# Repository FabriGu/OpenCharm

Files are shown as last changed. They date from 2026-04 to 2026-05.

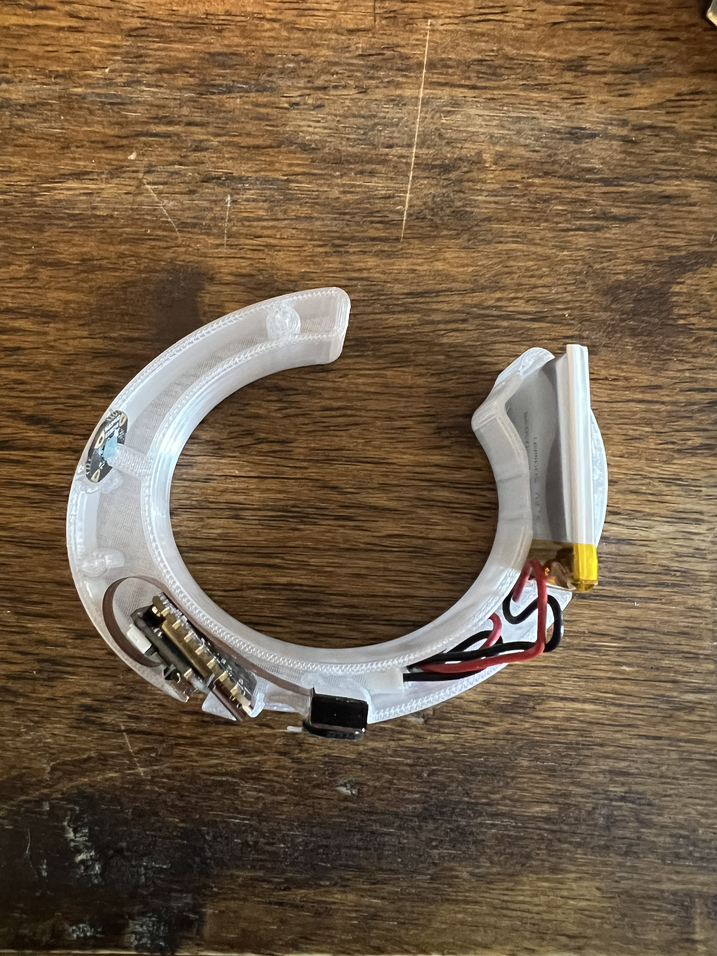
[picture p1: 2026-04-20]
assets/V0.1_Prototype/IMG_8304 2.jpeg

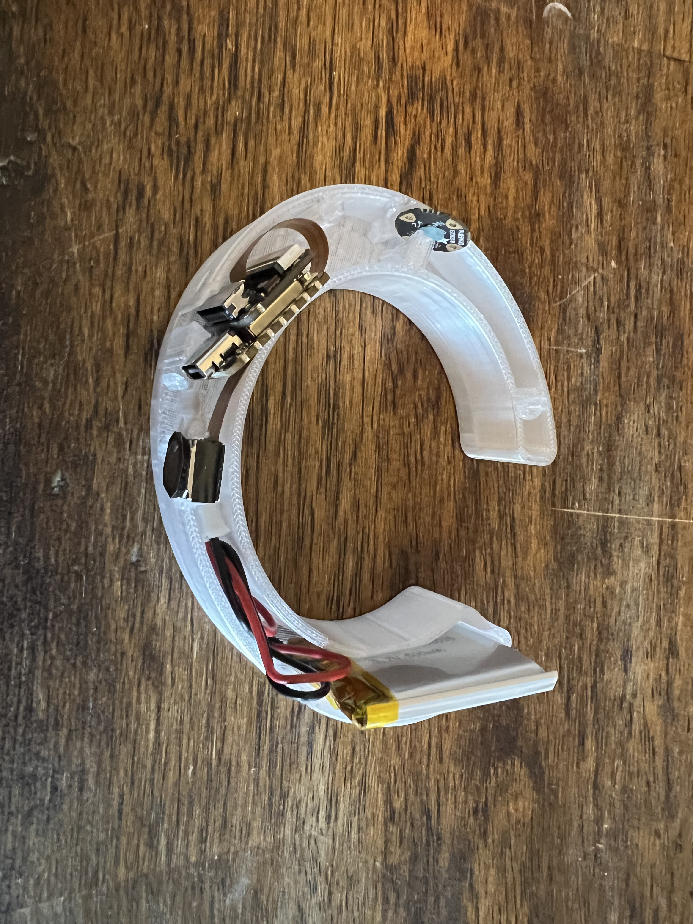
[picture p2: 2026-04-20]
assets/V0.1_Prototype/IMG_8305 2.jpeg

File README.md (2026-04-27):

# OpenCharm

A wearable that lets you talk to AI without being at your computer.

## The Idea

You shouldn't have to be sitting at a desk to use AI tools. OpenCharm is a tiny wrist-worn device that listens for voice commands, records what you say, and sends it to an AI agent that actually does stuff for you — runs commands, writes files, whatever you need. Results come back to your phone via Telegram.

Walk around. Be outside. Be cooking. Be anywhere. Touch grass. Just talk to your wrist and things happen on your machine.

## How It Works

```
┌──────────────────────────────────────────────┐
│      XIAO ESP32S3 Sense (on your wrist)      │
│  keyword spotting · mic · camera · LED       │
└──────────────────┬───────────────────────────┘
                   │ WiFi HTTP POST
                   ▼
┌──────────────────────────────────────────────┐
│       Relay Server (on your laptop)          │
│  Whisper transcription · session mgmt        │
│  Claude Code executor · Telegram bot         │
└──────────┬───────────────────┬───────────────┘
           │                   │
           ▼                   ▼
    Claude Code CLI      Telegram Bot
    (executes tasks)     (sends results)
```

1. **Say a keyword** — the bracelet runs an Edge Impulse ML model on-device to detect `RECORD`, `STOP`, `CAPTURE`, or `POST`.
2. **Record audio or snap a photo** — audio is captured at 16 kHz 16-bit mono; photos at 640x480 JPEG.
3. **Upload over WiFi** — the bracelet HTTP-POSTs the file to a FastAPI relay server on your local network.
4. **Transcribe and execute** — the relay runs Whisper (local, no API cost) to transcribe speech, then feeds the request to Claude Code.
5. **Get notified** — results are pushed to your phone via Telegram.

### Interaction Modes

| Input | Trigger | What happens |
|---|---|---|
| Voice command | Say **"Record"** → speak → say **"Stop"** (or 30 s timeout) | Audio recorded, uploaded, transcribed, executed |
| Photo | Say **"Capture"** | 3-second LED countdown, then JPEG captured and uploaded |
| Session | Buffer multiple audio/image captures, then say **"Post"** | Accumulated content sent as one batch to the AI |

## Why

AI tools are powerful but they chain you to a keyboard and screen. This project breaks that chain. It's about **freedom** — accessing the same AI capabilities from anywhere in your space, hands-free, eyes-free.

## Tech Stack

| Layer | Technology | Details |
|---|---|---|
| **MCU** | XIAO ESP32S3 Sense | 240 MHz dual-core, 8 MB flash, PSRAM, built-in mic + camera |
| **ML** | Edge Impulse / TFLite Micro | On-device keyword spotting (4 keywords + noise/unknown) |
| **Speech-to-Text** | faster-whisper | Runs locally on your laptop — no cloud API costs |
| **AI Execution** | Claude Code CLI | Subprocess with JSON stdin/stdout |
| **Relay Server** | Python / FastAPI | Async HTTP, session management, Telegram integration |
| **Notifications** | Telegram Bot API | Push results to your phone |
| **Firmware** | Arduino / PlatformIO | C++ with FreeRTOS on Core 1 for inference |

## Project Structure

```
OpenCharm/
├── firmware/                   ESP32S3 firmware (Arduino/PlatformIO)
│   ├── platformio.ini
│   ├── include/
│   │   └── config.h            WiFi, pin, ML threshold configuration
│   ├── lib/
│   │   └── ei-keyword-spotting/ Edge Impulse TFLite model library
│   └── src/
│       └── main.cpp            Main firmware: keywords, recording, camera, WiFi
│
├── relay/                      Python relay server
│   ├── relay_server.py         FastAPI server (audio upload, transcription, execution)
│   ├── claude_executor.py      Claude Code subprocess executor
│   ├── intent_parser.py        Voice command intent parsing
│   ├── requirements.txt
│   └── README.md
│
├── scripts/
│   ├── recording/              Serial audio recording utilities
│   │   ├── record_serial.py
│   │   ├── sample_recorder_local.py
│   │   └── recorder_firmware/
│   └── training/               ML training automation
│       ├── train_model.py      Automated Edge Impulse pipeline
│       ├── generate_tts_samples.py  Synthetic voice data via Google TTS
│       ├── clean_upload.py
│       └── requirements.txt
│
├── cad/                        3D-printable enclosure
│   └── V1/                     STL + STEP files (left/right halves)
│
├── docs/                       Documentation
│   ├── quick-start.md
│   ├── architecture.md
│   ├── network-architecture.md
│   ├── keyword-detection.md
│   ├── latency-analysis.md
│   ├── bom.md
│   └── ...
│
├── assets/                     Photos and media
│   └── V0.1_Prototype/
│
├── hermes-config/              Alternative AI integration notes
│
└── LICENSE                     MIT
```

## Quick Start

### Hardware

- 1x [Seeed XIAO ESP32S3 Sense](https://wiki.seeedstudio.com/xiao_esp32s3_getting_started/)
- USB-C cable
- (Optional) 3D-printed enclosure from `cad/V1/`

See `docs/bom.md` for the full bill of materials.

### Firmware

```bash
# Install PlatformIO CLI (or use VS Code extension)
pip install platformio

# Configure WiFi and relay IP
# Edit firmware/include/config.h:
#   WIFI_SSID, WIFI_PASSWORD, RELAY_IP, RELAY_PORT

cd firmware
pio run --target upload
pio device monitor        # watch serial output
```

### Relay Server

```bash
cd relay
pip install -r requirements.txt

# Create .env with your Telegram bot token (optional)
# TELEGRAM_BOT_TOKEN=...
# TELEGRAM_CHAT_ID=...

python relay_server.py
# Server starts on http://0.0.0.0:8080
```

### ML Model Training (Optional)

Only needed if you want to retrain the keyword detection model.

```bash
cd scripts/training
pip install -r requirements.txt

# Generate synthetic training samples
python generate_tts_samples.py

# Train on Edge Impulse and download the Arduino library
python train_model.py
```

See `docs/keyword-detection.md` for model details and threshold tuning.

## API Endpoints

The relay server exposes these endpoints for the bracelet:

| Endpoint | Method | Description |
|---|---|---|
| `/health` | GET | Health check |
| `/capture/audio` | POST | Upload and transcribe a WAV file |
| `/capture/image` | POST | Upload and analyze a JPEG |
| `/session/audio` | POST | Buffer audio in current session |
| `/session/image` | POST | Buffer image in current session |
| `/session/process` | POST | Process all buffered session content |
| `/session/execute` | POST | Send accumulated context to Claude Code |

## Status

Working prototype. Voice commands, photo capture, audio recording, AI execution, and Telegram feedback all functional. Actively iterating on ML model accuracy and form factor.

## License

[MIT](LICENSE)

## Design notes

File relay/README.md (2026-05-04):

# OpenCharm Relay Server

Receives images and audio from the XIAO ESP32S3 bracelet via HTTP POST, converts audio to OGG/Opus, and forwards to Telegram where Hermes Agent processes them.

## Setup

### 1. Install Dependencies

```bash
cd relay
python3 -m venv .venv
source .venv/bin/activate
pip install -r requirements.txt
```

### 2. Install FFmpeg (for audio conversion)

```bash
# macOS
brew install ffmpeg

# Ubuntu/Debian
sudo apt install ffmpeg
```

### 3. Create Telegram Bot

1. Open Telegram and message `@BotFather`
2. Send `/newbot`
3. Choose a name (e.g., "OpenCharm")
4. Choose a username (e.g., `opencharm_bot`)
5. Copy the HTTP API token

### 4. Get Your Chat ID

1. Send any message to your new bot
2. Visit: `https://api.telegram.org/bot<YOUR_TOKEN>/getUpdates`
3. Find `"chat":{"id":123456789}` in the JSON response
4. That number is your chat ID

### 5. Configure Environment

```bash
cp .env.example .env
# Edit .env with your token and chat ID
```

### 6. Run the Server

```bash
source .venv/bin/activate
python relay_server.py
```

Or with uvicorn directly:
```bash
uvicorn relay_server:app --host 0.0.0.0 --port 8080
```

## Endpoints

| Endpoint | Method | Description |
|---|---|---|
| `/` | GET | Status and last capture info |
| `/health` | GET | Health check for bracelet |
| `/capture/image` | POST | Receive JPEG, send to Telegram |
| `/capture/audio` | POST | Receive WAV, convert to OGG, send as voice |

## Testing with curl

### Test image upload:
```bash
curl -X POST http://localhost:8080/capture/image \
  -F "image=@test.jpg"
```

### Test audio upload:
```bash
curl -X POST http://localhost:8080/capture/audio \
  -F "audio=@test.wav"
```

## Bracelet Configuration

Set these in the bracelet firmware `config.h`:

```cpp
#define RELAY_IP    "192.168.x.x"  // Your laptop's IP
#define RELAY_PORT  8080
```

Find your IP with:
```bash
# macOS
ipconfig getifaddr en0

# Linux
hostname -I
```

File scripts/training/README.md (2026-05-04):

# Edge Impulse Keyword Spotting Training

Automated training scripts for the OpenCharm keyword spotting model.

## Keywords

- **RECORD** - Start audio recording
- **STOP** - Stop recording (don't process)
- **SNAP** - Take photo with countdown
- **SEND** - Process all accumulated content with AI

## Quick Start

### 1. Install Dependencies

```bash
cd scripts/training
pip install -r requirements.txt
```

### 2. Configure Credentials

```bash
cp .env.example .env
# Edit .env with your API keys
```

**Required:**
- `EDGE_IMPULSE_API_KEY` - Get from Edge Impulse Studio > Your Project > Dashboard > Keys

**Optional (for synthetic voice generation):**
- `GOOGLE_APPLICATION_CREDENTIALS` - Path to Google Cloud service account JSON

### 3. Generate Voice Samples

**Option A: Use Google TTS (automated)**
```bash
python generate_tts_samples.py
```

**Option B: Record your own voice**
Place WAV files (16kHz, mono, 1 second) in:
```
samples/
  record/
    record_001.wav
    record_002.wav
    ...
  stop/
    stop_001.wav
    ...
  snap/
  send/
  noise/
  unknown/
```

**Option C: Both (recommended)**
Generate TTS samples, then add your own recordings for better accuracy.

### 4. Train Model

```bash
python train_model.py
```

This will:
1. Upload samples to Edge Impulse
2. Configure the impulse (MFE + Transfer Learning)
3. Train the model
4. Download the Arduino library

### 5. Install in Firmware

The script will install the library to `firmware/lib/ei-keyword-spotting-new/`.

Manually update:
1. Back up the existing `ei-keyword-spotting` library if needed
2. Rename `ei-keyword-spotting-new` to `ei-keyword-spotting`
3. Update `main.cpp` include if needed

## Manual Training (Alternative)

If the automation doesn't work, you can train manually in Edge Impulse Studio:

1. Go to https://studio.edgeimpulse.com
2. Create new project
3. Upload samples from `./samples/` directory
4. Create impulse: Time Series → MFE → Classification
5. Train model
6. Download Arduino library
7. Extract to `firmware/lib/ei-keyword-spotting/`

## Tips for Better Accuracy

1. **Add your own voice samples** - TTS is good but your voice will be more accurate
2. **Record in your environment** - Background noise matters
3. **Vary your pronunciation** - Fast, slow, loud, quiet
4. **50+ samples per keyword minimum** - More is better
5. **Good noise/unknown class** - Prevents false positives

## Troubleshooting

### "API key not found"
- Make sure `.env` file exists with your `EDGE_IMPULSE_API_KEY`
- Get key from Edge Impulse Studio > Dashboard > Keys

### "Google TTS not available"
- Install: `pip install google-cloud-texttospeech`
- Set up credentials: https://cloud.google.com/text-to-speech/docs/quickstart

### "Training failed"
- Check Edge Impulse Studio for detailed error messages
- Make sure you have enough samples (50+ per keyword)
- Try reducing training cycles if memory issues

### "Model accuracy too low"
- Add more samples, especially your own voice
- Improve unknown/noise class diversity
- Try different DSP settings (MFE vs MFCC)

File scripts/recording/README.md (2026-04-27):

# ESP32 Keyword Sample Recorder

Record training samples directly through your ESP32's microphone for better keyword detection accuracy.

## Quick Start

### 1. Find your computer's IP address

```bash
# On Mac:
ipconfig getifaddr en0
```

### 2. Update the firmware with your IP

Edit `recorder_firmware/src/main.cpp`:
```cpp
#define SERVER_IP       "YOUR_IP_HERE"  // e.g., "192.168.1.181"
```

Also verify WiFi credentials match your network.

### 3. Flash the recorder firmware

```bash
cd recorder_firmware
pio run -t upload
```

### 4. Start the recording server

```bash
# In another terminal:
python sample_server.py
```

### 5. Record samples

1. Press the **button** on ESP32
2. LED turns **RED** - say the keyword clearly
3. **GREEN flash** = sample saved
4. Repeat until all samples collected

## How it works

- ESP32 records 2.5 seconds of audio when you press the button
- Audio is sent to your computer over WiFi
- The Python server automatically:
  - Detects where your voice is in the recording (VAD)
  - Centers the word in a perfect 1-second window
  - Saves it with the correct filename
- No timing pressure on you!

## After recording

Samples are saved to:
```
scripts/training/samples/
  record/record_real_001.wav, record_real_002.wav, ...
  stop/stop_real_001.wav, ...
  capture/capture_real_001.wav, ...
  post/post_real_001.wav, ...
```

Then:
1. Go to Edge Impulse Studio
2. Delete old samples (or keep some TTS for variety)
3. Upload the new real samples
4. Retrain the model
5. Download and flash the new Arduino library

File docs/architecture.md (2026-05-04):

# OpenCharm Network Architecture Diagrams

## System Overview

```
┌─────────────────────────────────────────────────────────────────────────┐
│                            OpenCharm System                              │
└─────────────────────────────────────────────────────────────────────────┘

┌──────────────┐         ┌──────────────┐         ┌──────────────┐
│  ESP32S3     │  WiFi   │ Relay Server │ Process │ Claude Code  │
│  Bracelet    │────────▶│  (FastAPI)   │────────▶│  Subprocess  │
│              │  HTTP   │              │ stdin/  │              │
│  - Camera    │         │  - Whisper   │ stdout  │  - Bash      │
│  - Mic (PDM) │         │  - Vision AI │         │  - Edit      │
│  - Keywords  │         │  - Telegram  │         │  - Read      │
│  - LED       │◀────────│  - Claude    │◀────────│  - Write     │
└──────────────┘  200 OK └──────────────┘ JSON    └──────────────┘
                              │
                              │ Telegram API
                              ▼
                         ┌──────────────┐
                         │   Telegram   │
                         │     Bot      │
                         │ (User Feed)  │
                         └──────────────┘
```

---

## Data Flow: Voice Command Execution

```
┌─────────────────────────────────────────────────────────────────────────┐
│ Example: User says "git status"                                         │
└─────────────────────────────────────────────────────────────────────────┘

1️⃣ ESP32 CAPTURE
┌──────────────┐
│   ESP32S3    │  User speaks "git status"
│              │  ↓
│ [RECORD]     │  Keyword detected → Start recording
│ [STOP]       │  Keyword detected → Stop recording
│              │  ↓
│ 16kHz WAV    │  Build WAV file (16kHz, 16-bit, mono)
│ Audio Buffer │
└──────────────┘
       │
       │ POST /capture/audio
       │ multipart/form-data
       │ Field: audio (audio/wav)
       ▼

2️⃣ RELAY PROCESSING
┌──────────────┐
│ Relay Server │  Receive HTTP POST
│              │  ↓
│ FastAPI      │  Save temp WAV file
│ Async        │  ↓
│              │  Whisper transcription
│ [Whisper]    │  "git status" (confidence: 0.95)
│  base model  │
└──────────────┘
       │
       │ HTTP 200 OK (immediate response to ESP32)
       │
       ├─────────────────────────────────────┐
       │                                     │
       │ Background Task                     │ Main Thread
       ▼                                     ▼
┌──────────────┐                    ┌──────────────┐
│   Telegram   │                    │   ESP32S3    │
│     Bot      │                    │              │
│              │                    │ LED: Success │
│ "You said:   │                    │ (Green flash)│
│  git status" │                    └──────────────┘
└──────────────┘
       │
       │ AI Processing continues...
       ▼

3️⃣ CLAUDE CODE INTEGRATION
┌──────────────┐
│ Relay Server │  Format task prompt
│              │  ↓
│              │  {
│              │    "type": "user",
│              │    "content": "Execute: git status"
│              │  }
│              │  ↓
│ [stdin pipe] │  Write JSON + newline
└──────────────┘
       │
       │ stdin stream
       │ (subprocess.PIPE)
       ▼
┌──────────────┐
│ Claude Code  │  Parse command
│  Subprocess  │  ↓
│              │  Understand: "Run git status"
│  --print     │  ↓
│  --stream    │  Check safety:
│              │  ✅ git status (read-only, safe)
│              │  ↓
│ [Bash tool]  │  Execute: git status
│              │  ↓
│              │  Capture output:
│              │  "On branch wifi
│              │   Changes not staged:
│              │     modified: relay/.env"
└──────────────┘
       │
       │ stdout stream
       │ (JSON lines)
       ▼
┌──────────────┐
│ Relay Server │  Read stdout line-by-line
│              │  ↓
│ [stdout      │  Parse JSON response
│  reader]     │  ↓
│              │  Format for Telegram:
│              │  ```
│              │  On branch wifi
│              │  M relay/.env
│              │  ```
└──────────────┘
       │
       │ Send to Telegram
       ▼
┌──────────────┐
│   Telegram   │
│     Bot      │
│              │
│ *Git Status* │
│              │
│ ```          │
│ On branch    │
│   wifi       │
│ M relay/.env │
│ ```          │
└──────────────┘

4️⃣ COMPLETION
       │
       │ Log success metrics
       ▼
   [Complete]
   Total time: 3.5s
   - Capture: 1.0s
   - Transfer: 0.2s
   - Whisper: 1.5s
   - Claude: 0.5s
   - Telegram: 0.3s
```

---

## Data Flow: Image Analysis

```
┌─────────────────────────────────────────────────────────────────────────┐
│ Example: User says "CAPTURE" then "POST"                                │
└─────────────────────────────────────────────────────────────────────────┘

1️⃣ ESP32 CAPTURE
┌──────────────┐
│   ESP32S3    │  User says "CAPTURE"
│              │  ↓
│ [CAPTURE]    │  Keyword detected
│ countdown    │  ↓
│              │  3... 2... 1... *flash*
│ [OV2640]     │  ↓
│ Camera       │  Capture JPEG (640x480)
│              │  ↓
│ Session      │  Buffer in session (not processed yet)
│ buffer       │
└──────────────┘
       │
       │ POST /session/image
       │ (buffered, not analyzed)
       ▼
┌──────────────┐
│ Relay Server │  Store in session_buffer
│              │
│ session:     │  {
│  images: [1] │    "image_files": [
│  audio: [0]  │      {"data": bytes, "timestamp": "..."}
│              │    ]
│              │  }
└──────────────┘
       │
       │ User says "POST"
       ▼

2️⃣ SESSION PROCESSING
┌──────────────┐
│   ESP32S3    │  POST /session/process
│              │  ↓
│ [POST]       │  Trigger processing of ALL buffered content
└──────────────┘
       │
       ▼
┌──────────────┐
│ Relay Server │  Combine session content:
│              │  - 1 image (JPEG)
│              │  - 0 audio files
│              │  ↓
│              │  Prepare multi-modal prompt
└──────────────┘
       │
       │ Format for Claude Code
       ▼

3️⃣ MULTI-MODAL ANALYSIS
┌──────────────┐
│ Relay Server │  {
│              │    "type": "user",
│              │    "content": "Analyze workspace image",
│              │    "attachments": [
│              │      {
│              │        "type": "image",
│              │        "mime_type": "image/jpeg",
│              │        "data": "base64..."
│              │      }
│              │    ]
│              │  }
└──────────────┘
       │
       │ stdin
       ▼
┌──────────────┐
│ Claude Code  │  Receive image + prompt
│  Subprocess  │  ↓
│              │  Vision analysis:
│ [Vision]     │  - Sees desk with laptop
│              │  - Code on screen (C++)
│              │  - Notes: indentation inconsistent
│              │  ↓
│              │  Generate suggestion:
│              │  "Fix indentation in main.cpp lines 45-60"
│              │  ↓
│ [Edit tool]  │  Execute fix:
│              │  Edit /path/to/main.cpp
│              │  - Fix indentation
│              │  ↓
│              │  Return result:
│              │  "Fixed indentation in main.cpp"
└──────────────┘
       │
       │ stdout
       ▼
┌──────────────┐
│ Relay Server │  Parse response
│              │  ↓
│              │  Clear session buffer
│              │  ↓
│              │  Send to Telegram + ESP32
└──────────────┘
       │
       ├───────────────────┐
       │                   │
       ▼                   ▼
┌──────────────┐    ┌──────────────┐
│   Telegram   │    │   ESP32S3    │
│              │    │              │
│ "I see your  │    │ LED: Success │
│  workspace.  │    │ (Green)      │
│  Fixed       │    └──────────────┘
│  indentation │
│  in main.cpp"│
└──────────────┘
```

---

## Safety & Confirmation Flow

```
┌─────────────────────────────────────────────────────────────────────────┐
│ Example: User says "delete old files"                                   │
└─────────────────────────────────────────────────────────────────────────┘

1️⃣ COMMAND RECEIVED
┌──────────────┐
│   ESP32S3    │  Voice: "delete old files"
│              │  ↓
│ [Audio]      │  Transcription: "delete old files"
└──────────────┘
       │
       ▼
┌──────────────┐
│ Relay Server │  Whisper → "delete old files"
│              │  ↓
│              │  Send to Claude Code
└──────────────┘
       │
       ▼

2️⃣ CLAUDE ANALYSIS
┌──────────────┐
│ Claude Code  │  Understand command
│              │  ↓
│              │  Generate plan:
│              │  - find . -name "*.old" -type f
│              │  - rm *.old
│              │  ↓
│ [Safety      │  Check safety rules:
│  check]      │  ⚠️ DANGEROUS: 'rm' command detected
│              │  ↓
│              │  Request confirmation
└──────────────┘
       │
       │ Return: {
       │   "type": "confirmation_required",
       │   "action": "Delete 5 .old files",
       │   "command": "rm file1.old file2.old ..."
       │ }
       ▼

3️⃣ CONFIRMATION REQUEST
┌──────────────┐
│ Relay Server │  Parse response
│              │  ↓
│ [Action      │  Detect confirmation_required
│ Confirm]     │  ↓
│              │  Send to Telegram:
└──────────────┘
       │
       ▼
┌──────────────┐
│   Telegram   │  ⚠️ *Action Confirmation Required*
│     Bot      │
│              │  Command: `rm file1.old file2.old ...`
│ [Inline      │  Context: Delete 5 .old files
│  keyboard]   │
│              │  [✅ Approve]  [❌ Deny]
└──────────────┘
       │
       │ User clicks ✅ Approve
       │ (or timeout after 60s → auto-deny)
       ▼

4️⃣ EXECUTION OR CANCELLATION
┌──────────────┐
│ Relay Server │  Receive approval
│              │  ↓
│              │  Send to Claude Code:
│              │  {
│              │    "type": "user",
│              │    "content": "Approved: execute deletion"
│              │  }
└──────────────┘
       │
       ▼
┌──────────────┐
│ Claude Code  │  Execute command
│              │  ↓
│ [Bash tool]  │  rm file1.old file2.old ...
│              │  ↓
│              │  Return: "Deleted 5 files"
└──────────────┘
       │
       ▼
┌──────────────┐
│   Telegram   │  ✅ *Deletion Complete*
│              │
│              │  Deleted 5 files:
│              │  - file1.old
│              │  - file2.old
│              │  - ...
└──────────────┘

Alternative: User clicks ❌ Deny
       │
       ▼
┌──────────────┐
│ Relay Server │  Send cancellation
│              │  ↓
│ Claude Code  │  Abort operation
│              │  ↓
│ Telegram     │  ❌ *Action Cancelled*
│              │  Deletion request denied by user
└──────────────┘
```

---

## Subprocess Communication Pattern

```
┌─────────────────────────────────────────────────────────────────────────┐
│ Relay Server ↔ Claude Code Subprocess (stdin/stdout)                    │
└─────────────────────────────────────────────────────────────────────────┘

┌──────────────────────────┐         ┌──────────────────────────┐
│      Relay Server        │         │    Claude Code Process   │
│      (Python/FastAPI)    │         │    (Node.js subprocess)  │
└──────────────────────────┘         └──────────────────────────┘

INITIALIZATION
─────────────────────────────────────────────────────────────────

1. Start subprocess:
   ┌────────────────────┐
   │ asyncio.create_    │
   │ subprocess_exec(   │
   │   'claude',        │
   │   '--print',       │
   │   '--stream-json'  │
   │ )                  │
   └────────────────────┘
          │
          ├──── stdin  = PIPE ───────▶
          ├──── stdout = PIPE ◀───────
          └──── stderr = PIPE ◀───────

2. Create async tasks:
   - Writer task (stdin)
   - Reader task (stdout)
   - Error reader (stderr)

COMMUNICATION
─────────────────────────────────────────────────────────────────

Input Queue                              Output Queue
┌────────────┐                          ┌────────────┐
│  Message 1 │                          │ Response 1 │
│  Message 2 │                          │ Response 2 │
│  Message 3 │                          │ Response 3 │
└────────────┘                          └────────────┘
     │                                        ▲
     │                                        │
     ▼                                        │
┌──────────────┐                      ┌──────────────┐
│ Writer Task  │  stdin (JSON line)   │ Reader Task  │
│              │─────────────────────▶│              │
│ while True:  │                      │ while True:  │
│   msg = await│                      │   line =     │
│   queue.get()│                      │   await      │
│   write_json │                      │   readline() │
│   await drain│                      │   parse_json │
│              │                      │   queue.put  │
└──────────────┘                      └──────────────┘
                                             │
                                             ▼
                                      ┌──────────────┐
                                      │ FastAPI      │
                                      │ endpoint     │
                                      │ awaits       │
                                      │ response     │
                                      └──────────────┘

SAMPLE EXCHANGE
─────────────────────────────────────────────────────────────────

Relay Server sends:
{
  "type": "user",
  "content": "Execute: git status"
}

Claude Code responds (streaming):
{
  "type": "partial",
  "content": "Running git"
}
{
  "type": "partial",
  "content": " status..."
}
{
  "type": "tool_use",
  "tool": "Bash",
  "command": "git status"
}
{
  "type": "tool_result",
  "output": "On branch wifi\nChanges not staged..."
}
{
  "type": "message",
  "content": "On branch wifi\nChanges not staged for commit:\n  modified: relay/.env"
}

HEALTH MONITORING
─────────────────────────────────────────────────────────────────

┌──────────────┐
│ Health Check │  Every 30 seconds
│   Task       │
│              │  Check:
│ while True:  │  - process.returncode is None ✓
│   sleep(30)  │  - stdin writable ✓
│   if dead:   │  - stdout readable ✓
│     restart  │
└──────────────┘
     │
     │ If process dies
     ▼
┌──────────────┐
│  Restart     │  1. Terminate gracefully
│  Procedure   │  2. Wait 5s
│              │  3. Kill if needed
│  1. term()   │  4. Restart subprocess
│  2. wait(5s) │  5. Clear buffers
│  3. kill()   │  6. Resume operation
│  4. start()  │
└──────────────┘

ERROR HANDLING
─────────────────────────────────────────────────────────────────

Scenario 1: JSON Parse Error
  stdin: {invalid json}
  stdout: {"type": "error", "message": "Invalid JSON"}
  → Log error, send fallback response

Scenario 2: Process Crash
  process.returncode = -11 (SIGSEGV)
  → Restart subprocess, retry last command

Scenario 3: Timeout (no response after 60s)
  → Send SIGTERM, restart, return timeout error

Scenario 4: Permission Denied
  stdout: {"type": "error", "code": "EACCES"}
  → Request user confirmation via Telegram
```

---

## Network Topology

```
┌─────────────────────────────────────────────────────────────────────────┐
│                    Local Network (192.168.1.0/24)                       │
└─────────────────────────────────────────────────────────────────────────┘

                      ┌──────────────┐
                      │  WiFi Router │
                      │  or Hotspot  │
                      │              │
                      │  2.4GHz only │
                      │  (ESP32 req) │
                      └──────────────┘
                             │
                 ┌───────────┼───────────┐
                 │                       │
                 ▼                       ▼
        ┌──────────────┐        ┌──────────────┐
        │   ESP32S3    │        │    Laptop    │
        │  192.168.1.x │        │ 192.168.1.181│
        │              │        │              │
        │  Port: N/A   │        │ Port: 8080   │
        │  (client)    │        │ (server)     │
        └──────────────┘        └──────────────┘
                                       │
                                       │ localhost
                                       │
                                ┌──────┼──────┐
                                │             │
                                ▼             ▼
                        ┌──────────┐  ┌──────────┐
                        │  Relay   │  │  Claude  │
                        │  Server  │  │   Code   │
                        │  :8080   │  │  (sub-   │
                        │          │  │ process) │
                        └──────────┘  └──────────┘
                                │
                                │ HTTPS
                                │ (internet)
                                ▼
                        ┌──────────────┐
                        │   External   │
                        │   Services   │
                        │              │
                        │ - Telegram   │
                        │ - OpenAI API │
                        └──────────────┘

FIREWALL RULES (Laptop)
────────────────────────
Inbound:
  ✅ TCP 8080 (from 192.168.1.0/24)  → Relay Server
  ❌ All other ports                  → Blocked

Outbound:
  ✅ HTTPS (443)                      → Telegram, OpenAI
  ✅ HTTP (11434)                     → Ollama (localhost)
  ❌ All other                        → Blocked

NETWORK REQUIREMENTS
────────────────────────
ESP32 Requirements:
  - 2.4GHz WiFi (NOT 5GHz)
  - WPA2 Personal
  - Signal strength: > -70 dBm
  - Latency: < 50ms

Relay Server Requirements:
  - Same subnet as ESP32
  - Fixed IP or DHCP reservation
  - Port 8080 accessible

Demo Setup:
  - Use WiFi hotspot (laptop or phone)
  - Disable firewall or allow port 8080
  - Test connectivity: curl http://192.168.1.181:8080/health
```

---

## Latency Analysis

```
┌─────────────────────────────────────────────────────────────────────────┐
│                          Latency Breakdown                               │
└─────────────────────────────────────────────────────────────────────────┘

Voice Command: "git status"

│
│ User speaks
▼ ──────────────────────────────────────────────────────────────
│ 1️⃣ KEYWORD DETECTION (on ESP32)
│    - Continuous inference: 100-200ms per slice
│    - Word detection: 300-500ms (3-5 slices)
│    - Latency: ~400ms average
▼ ──────────────────────────────────────────────────────────────
│ 2️⃣ AUDIO CAPTURE (on ESP32)
│    - Recording duration: variable (user speech)
│    - Example: "git status" = 1.0s
│    - Latency: 1000ms (user-controlled)
▼ ──────────────────────────────────────────────────────────────
│ 3️⃣ KEYWORD STOP (on ESP32)
│    - "STOP" detection: 300-500ms
│    - Latency: ~400ms
▼ ──────────────────────────────────────────────────────────────
│ 4️⃣ NETWORK TRANSFER (ESP32 → Relay)
│    - WAV file size: ~32KB (1s @ 16kHz)
│    - WiFi speed: 1-5 Mbps (2.4GHz)
│    - Transfer time: 50-150ms
│    - Latency: ~100ms
▼ ──────────────────────────────────────────────────────────────
│ 5️⃣ WHISPER TRANSCRIPTION (on Laptop)
│    - Model: base (74M params)
│    - Audio: 1.0s
│    - CPU: M-series Mac
│    - Latency: 800-1500ms (varies with CPU)
│    - Average: ~1200ms
▼ ──────────────────────────────────────────────────────────────
│ 6️⃣ CLAUDE CODE EXECUTION (on Laptop)
│    - Parse command: 50ms
│    - Execute tool (git status): 100-300ms
│    - Format response: 50ms
│    - Latency: ~200ms (simple commands)
│    - Latency: ~2000ms (complex operations)
▼ ──────────────────────────────────────────────────────────────
│ 7️⃣ TELEGRAM SEND (Laptop → Internet → Telegram)
│    - API call latency: 200-500ms
│    - Latency: ~300ms
▼ ──────────────────────────────────────────────────────────────
│ User sees result in Telegram
│

TOTAL LATENCY BUDGET (excluding user speech time)
──────────────────────────────────────────────────
Optimistic:  400 + 400 + 100 + 800  + 200  + 200  = 2100ms (~2s)
Realistic:   400 + 400 + 100 + 1200 + 500  + 300  = 2900ms (~3s)
Pessimistic: 500 + 500 + 150 + 1500 + 2000 + 500  = 5150ms (~5s)

OPTIMIZATION STRATEGIES
───────────────────────
1. Use Whisper 'tiny' model:   -500ms (but worse accuracy)
2. Use Whisper 'base' model:    Current (good balance)
3. Parallel Telegram send:     -200ms (don't wait for send)
4. Cache common commands:      -500ms (skip Claude Code)
5. Pre-warm subprocess:        -100ms (avoid cold start)
6. Local WiFi optimization:    -50ms  (disable power save)

TARGET FOR DEMO
───────────────
Goal: < 3 seconds total (excluding user speech)
      ✅ Achievable with current architecture
      ✅ Use 'base' Whisper model
      ✅ Pre-warm Claude Code subprocess
      ✅ Optimize network (disable WiFi power save)
```

---

## Comparison: Architecture Options

```
┌─────────────────────────────────────────────────────────────────────────┐
│                      Architecture Comparison                             │
└─────────────────────────────────────────────────────────────────────────┘

OPTION A: Subprocess stdin/stdout (RECOMMENDED)
────────────────────────────────────────────────
┌──────────┐    ┌──────────┐    ┌──────────┐
│ ESP32S3  │───▶│  Relay   │───▶│  Claude  │
│          │◀───│  Server  │◀───│   Code   │
│  HTTP    │    │  Python  │    │  (stdin/ │
│          │    │          │    │  stdout) │
└──────────┘    └──────────┘    └──────────┘

Pros:
  ✅ Native Claude Code interface
  ✅ Streaming responses (progress updates)
  ✅ Low latency (no network overhead)
  ✅ Session management built-in
  ✅ Full tool access (Bash, Edit, Read, etc.)
  ✅ Local execution (no cloud deps)

Cons:
  ⚠️ Process lifecycle management needed
  ⚠️ Memory usage (long-running process)
  ⚠️ stdout parsing required

Latency: ~200-500ms (local execution)
Reliability: High (local, no network)
Complexity: Medium (subprocess management)

────────────────────────────────────────────────

OPTION B: HTTP API (future possibility)
────────────────────────────────────────────────
┌──────────┐    ┌──────────┐    ┌──────────┐
│ ESP32S3  │───▶│  Relay   │───▶│  Claude  │
│          │◀───│  Server  │◀───│   Code   │
│  HTTP    │    │  Python  │    │  HTTP    │
│          │    │  httpx   │    │  Server  │
└──────────┘    └──────────┘    └──────────┘

Pros:
  ✅ Simpler communication (REST API)
  ✅ Easier to test (curl, Postman)
  ✅ Stateless (each request independent)
  ✅ Load balancing possible

Cons:
  ❌ Claude Code doesn't expose HTTP API yet
  ⚠️ Higher latency (HTTP overhead)
  ⚠️ No streaming (unless WebSocket)
  ⚠️ Session management manual

Latency: ~300-800ms (HTTP round-trip)
Reliability: High (HTTP well-tested)
Complexity: Low (standard REST)

────────────────────────────────────────────────

OPTION C: Direct ESP32 → Claude Code (not viable)
────────────────────────────────────────────────
┌──────────┐                    ┌──────────┐
│ ESP32S3  │───────────────────▶│  Claude  │
│          │◀───────────────────│   Code   │
│  HTTPS?  │                    │  ???     │
│          │                    │          │
└──────────┘                    └──────────┘

Pros:
  ✅ Fewer hops (lower latency)
  ✅ Simpler architecture

Cons:
  ❌ ESP32 limited HTTPS support
  ❌ No Whisper on ESP32 (need cloud API)
  ❌ No way to run Claude Code on ESP32
  ❌ Still need relay for AI processing
  ❌ Certificate validation issues

Verdict: NOT VIABLE (need relay anyway)

────────────────────────────────────────────────

OPTION D: Cloud Relay (AWS Lambda, etc.)
────────────────────────────────────────────────
┌──────────┐    ┌──────────┐    ┌──────────┐
│ ESP32S3  │───▶│   AWS    │───▶│  Claude  │
│          │◀───│  Lambda  │◀───│   Code   │
│  HTTPS   │    │  Relay   │    │  API?    │
│          │    │          │    │          │
└──────────┘    └──────────┘    └──────────┘

Pros:
  ✅ Scalable (multiple devices)
  ✅ Always available (no laptop needed)
  ✅ Distributed (geographic redundancy)

Cons:
  ❌ Higher latency (internet round-trip)
  ❌ More failure points (ESP32 → AWS → Claude)
  ❌ Demo reliability depends on internet
  ❌ Cost (API calls, Lambda invocations)
  ❌ Claude Code not designed for cloud

Latency: ~1000-2000ms (internet overhead)
Reliability: Medium (multiple network hops)
Complexity: High (cloud infrastructure)

Verdict: Overkill for single-device demo

────────────────────────────────────────────────

RECOMMENDATION: Option A (Subprocess stdin/stdout)
Reasons:
  1. ✅ Native Claude Code interface
  2. ✅ Lowest latency (local execution)
  3. ✅ Best demo reliability (no cloud deps)
  4. ✅ Streaming for progress updates
  5. ✅ Full tool ecosystem access
```

---

## End of Architecture Diagrams

**Next:** See `network-architecture.md` for detailed implementation guide

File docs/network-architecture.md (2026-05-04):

# OpenCharm Network Architecture Design

**Author:** Network Infrastructure Design Agent
**Date:** 2026-03-25
**Purpose:** Design communication layer for ESP32S3 → Relay Server → Claude Code integration

---

## Executive Summary

This document proposes a **hybrid HTTP + subprocess stdin/stdout** architecture for connecting the OpenCharm ESP32S3 device to Claude Code through a relay server. The design prioritizes **demo reliability**, **action safety**, and **minimal firmware changes**.

### Key Recommendations
1. **Keep existing ESP32 HTTP interface** (don't touch firmware)
2. **Use subprocess stdin/stdout** for Claude Code communication (native, reliable)
3. **Implement action confirmation layer** before execution
4. **Add WebSocket for real-time progress updates** (optional, demo enhancement)

---

## Current Architecture Analysis

### ESP32S3 → Relay Server (EXISTING - DO NOT CHANGE)
```
Protocol:     HTTP POST (multipart/form-data)
Transport:    WiFi → Local network
Endpoints:
  - POST /capture/image          → Direct processing
  - POST /capture/audio          → Direct processing
  - POST /session/image          → Session buffer
  - POST /session/audio          → Session buffer
  - POST /session/process        → Trigger AI analysis
Server:       FastAPI (uvicorn) on 192.168.1.181:8080
Format:       Multipart form data (image/jpeg, audio/wav)
Processing:   Async handlers with background tasks
AI Backend:   OpenAI GPT-4o, Ollama (local/school), Anthropic
Output:       Telegram bot messages
```

**Characteristics:**
- ✅ **Reliable:** HTTP is well-tested, timeout handling works
- ✅ **Async:** FastAPI async handlers don't block ESP32
- ✅ **Proven:** Currently working in production
- ⚠️ **One-way:** ESP32 sends, gets HTTP 200, no real-time feedback
- ⚠️ **Fixed workflow:** Hard to add new actions without firmware update

---

## Proposed Architecture: Relay Server → Claude Code

### Option 1: Subprocess stdin/stdout (RECOMMENDED)

```python
# In relay_server.py
import asyncio
import json

class ClaudeCodeInterface:
    def __init__(self):
        self.process = None
        self.input_queue = asyncio.Queue()
        self.output_queue = asyncio.Queue()

    async def start(self):
        """Start Claude Code subprocess with streaming I/O"""
        self.process = await asyncio.create_subprocess_exec(
            'claude', '--print',
            '--input-format', 'stream-json',
            '--output-format', 'stream-json',
            '--include-partial-messages',
            '--replay-user-messages',
            stdin=asyncio.subprocess.PIPE,
            stdout=asyncio.subprocess.PIPE,
            stderr=asyncio.subprocess.PIPE,
            cwd='/Users/fabrizioguccione/Projects/OpenCharm'
        )

        # Start reader/writer tasks
        asyncio.create_task(self._read_output())
        asyncio.create_task(self._write_input())

    async def _write_input(self):
        """Stream JSON messages to Claude Code stdin"""
        while True:
            message = await self.input_queue.get()
            json_str = json.dumps(message) + '\n'
            self.process.stdin.write(json_str.encode())
            await self.process.stdin.drain()

    async def _read_output(self):
        """Stream JSON responses from Claude Code stdout"""
        while True:
            line = await self.process.stdout.readline()
            if not line:
                break
            try:
                response = json.loads(line.decode())
                await self.output_queue.put(response)
            except json.JSONDecodeError:
                logger.warning(f"Invalid JSON from Claude: {line}")

    async def send_task(self, task: dict, context: dict) -> dict:
        """Send a task to Claude Code and get response"""
        # Format prompt with context
        prompt = self._format_prompt(task, context)

        # Send message
        message = {
            "type": "user",
            "content": prompt,
            "attachments": context.get("attachments", [])
        }
        await self.input_queue.put(message)

        # Collect response chunks
        full_response = ""
        while True:
            chunk = await self.output_queue.get()

            # Handle partial messages (streaming)
            if chunk.get("type") == "partial":
                full_response += chunk.get("content", "")
                # Optional: Send progress via WebSocket

            # Handle complete messages
            elif chunk.get("type") == "message":
                full_response += chunk.get("content", "")
                break

        return {"response": full_response}

    def _format_prompt(self, task: dict, context: dict) -> str:
        """Format task into Claude Code prompt"""
        task_type = task.get("type")

        if task_type == "analyze_image":
            return f"""Analyze this image from the OpenCharm wearable device.

Context:
- Captured: {context.get('timestamp')}
- User request: {context.get('voice_command', 'None')}

Task: Provide brief, actionable feedback about the image.
Respond in 1-2 sentences, imperative voice."""

        elif task_type == "voice_command":
            return f"""Execute this voice command from the OpenCharm device.

Voice input: "{context.get('transcription')}"
Location: /Users/fabrizioguccione/Projects/OpenCharm

SAFETY RULES:
1. NEVER run destructive operations without explicit confirmation
2. File operations limited to project directory
3. No network operations (except localhost)
4. git operations allowed (read-only preferred)

Execute the command if safe, or explain what you would do if confirmation needed."""

        return "Unknown task type"
```

**Advantages:**
- ✅ **Native interface:** Claude Code designed for stdin/stdout
- ✅ **Streaming:** Partial messages for progress updates
- ✅ **Reliable:** No network layer to fail
- ✅ **Session management:** Built into Claude Code
- ✅ **Tool execution:** Full access to Bash, Edit, Read, etc.
- ✅ **Context aware:** Claude can read codebase files

**Disadvantages:**
- ⚠️ Process lifecycle management (restart on crash)
- ⚠️ Memory usage (long-running process)
- ⚠️ No direct Telegram integration (relay must forward)

---

### Option 2: HTTP API (BACKUP - if subprocess fails)

```python
# If Claude Code adds HTTP API in the future
import httpx

async def send_to_claude_http(prompt: str, files: dict = None):
    async with httpx.AsyncClient() as client:
        response = await client.post(
            "http://localhost:5555/v1/chat",
            json={
                "messages": [{"role": "user", "content": prompt}],
                "files": files,
                "cwd": "/Users/fabrizioguccione/Projects/OpenCharm"
            },
            timeout=120.0
        )
        return response.json()
```

**Note:** Claude Code doesn't currently expose HTTP API, but this would be simpler if available.

---

### Option 3: WebSocket for Real-Time Updates (ENHANCEMENT)

```python
# Add WebSocket endpoint to relay server for demo feedback
from fastapi import WebSocket

@app.websocket("/ws/progress")
async def websocket_endpoint(websocket: WebSocket):
    await websocket.accept()

    # Register websocket for progress updates
    active_connections.add(websocket)

    try:
        while True:
            # Keep connection alive, send progress updates
            data = await websocket.receive_text()
    finally:
        active_connections.remove(websocket)

async def broadcast_progress(message: str):
    """Send progress update to all connected clients"""
    for ws in active_connections:
        await ws.send_json({"type": "progress", "message": message})
```

**Use case:** Demo dashboard showing real-time processing status
- "Transcribing audio..."
- "Analyzing image with Claude Vision..."
- "Executing code change..."
- "✓ Complete"

---

## Security & Safety Layer

### Action Confirmation Strategy

```python
class ActionConfirmation:
    """Safety layer for Claude Code actions"""

    # Whitelist: Auto-approve safe operations
    SAFE_COMMANDS = {
        'git status', 'git log', 'git diff',
        'ls', 'pwd', 'cat',
        'grep', 'find', 'head', 'tail'
    }

    # Require confirmation
    DANGEROUS_PATTERNS = [
        r'rm -rf',
        r'sudo',
        r'chmod',
        r'git push',
        r'npm install',
        r'pip install',
    ]

    async def should_confirm(self, command: str) -> bool:
        """Check if command needs user confirmation"""
        # Allow whitelisted commands
        if command.strip() in self.SAFE_COMMANDS:
            return False

        # Check dangerous patterns
        for pattern in self.DANGEROUS_PATTERNS:
            if re.search(pattern, command):
                return True

        # Check file write operations outside project
        if 'write' in command.lower() and '/Users/fabrizioguccione/Projects/OpenCharm' not in command:
            return True

        return False

    async def request_confirmation(self, command: str, context: str) -> bool:
        """Request confirmation via Telegram"""
        message = f"""⚠️ *Action Confirmation Required*

Command: `{command}`
Context: {context}

Reply with:
✅ /approve - Execute
❌ /deny - Cancel
"""
        await send_telegram_text(message)

        # Wait for user response (with timeout)
        response = await wait_for_telegram_response(timeout=60)
        return response == "/approve"
```

### File System Sandboxing

```python
ALLOWED_PATHS = [
    '/Users/fabrizioguccione/Projects/OpenCharm',
    '/tmp/opencharm-*'  # Temp files
]

def validate_path(path: str) -> bool:
    """Ensure file operations stay within project"""
    abs_path = os.path.abspath(path)
    return any(abs_path.startswith(allowed) for allowed in ALLOWED_PATHS)
```

---

## Message Flow Diagrams

### Flow 1: Voice Command → Code Execution

```
1. ESP32 → Relay Server
   POST /capture/audio → WAV file

2. Relay Server → Whisper
   Transcribe → "git status"

3. Relay Server → Claude Code (subprocess)
   stdin: {"type": "user", "content": "Execute: git status"}

4. Claude Code
   - Understands command
   - Uses Bash tool: git status
   - Returns output

5. Relay Server → Telegram
   Send formatted result

6. Relay Server → ESP32
   HTTP 200 OK (ESP32 LED feedback)
```

### Flow 2: Image Analysis → Actionable Feedback

```
1. ESP32 → Relay Server
   POST /capture/image → JPEG file

2. Relay Server → Claude Code
   stdin: {
     "type": "user",
     "content": "Analyze this workspace image",
     "attachments": [{"type": "image", "data": "base64..."}]
   }

3. Claude Code
   - Vision analysis
   - Suggests code improvement
   - Uses Edit tool to apply fix

4. Relay Server → Telegram
   "I see your desk setup. Fixed indentation in main.cpp"

5. Relay Server → ESP32
   HTTP 200 OK
```

### Flow 3: Session Workflow (RECORD → SNAP → POST)

```
1. Voice: "RECORD"
   ESP32 starts recording

2. Voice: "STOP"
   POST /session/audio → Buffered

3. Voice: "CAPTURE"
   POST /session/image → Buffered

4. Voice: "POST"
   POST /session/process → Process ALL

5. Relay Server → Claude Code
   stdin: {
     "type": "user",
     "content": "Context: User said '{transcription}' while showing image",
     "attachments": [{"type": "image", ...}, {"type": "audio", ...}]
   }

6. Claude Code
   - Multi-modal analysis
   - Executes appropriate tools
   - Returns comprehensive response
```

---

## Error Handling & Resilience

### Subprocess Management

```python
class ClaudeCodeManager:
    """Manage Claude Code subprocess lifecycle"""

    async def start_with_retry(self, max_retries: int = 3):
        """Start subprocess with exponential backoff"""
        for attempt in range(max_retries):
            try:
                await self.start()
                logger.info("Claude Code subprocess started")
                return
            except Exception as e:
                wait_time = 2 ** attempt
                logger.error(f"Subprocess start failed (attempt {attempt+1}): {e}")
                await asyncio.sleep(wait_time)

        raise RuntimeError("Failed to start Claude Code subprocess")

    async def health_check(self):
        """Periodic health check (heartbeat)"""
        while True:
            await asyncio.sleep(30)

            if self.process.returncode is not None:
                logger.error("Claude Code subprocess died! Restarting...")
                await self.start_with_retry()

    async def graceful_shutdown(self):
        """Clean shutdown on server stop"""
        if self.process:
            self.process.terminate()
            try:
                await asyncio.wait_for(self.process.wait(), timeout=5)
            except asyncio.TimeoutError:
                self.process.kill()
```

### Network Resilience

```python
# WiFi disconnect handling (already in ESP32 firmware)
# - Auto-reconnect on connection loss
# - Health check endpoint: GET /health
# - WiFi power save disabled for max performance

# Relay server timeouts
HTTP_TIMEOUT_MS = 30000          # 30s for normal operations
AI_TIMEOUT_MS = 120000           # 2min for AI processing
CLAUDE_CODE_TIMEOUT_MS = 180000  # 3min for complex operations

# Retry logic
async def send_with_retry(func, *args, max_retries=3, **kwargs):
    """Retry failed operations with exponential backoff"""
    for attempt in range(max_retries):
        try:
            return await func(*args, **kwargs)
        except Exception as e:
            if attempt == max_retries - 1:
                raise
            wait_time = 2 ** attempt
            logger.warning(f"Retry {attempt+1}/{max_retries} after {wait_time}s: {e}")
            await asyncio.sleep(wait_time)
```

---

## Demo Reliability Considerations

### Making Demos Bulletproof

1. **Pre-Demo Checklist**
   ```bash
   # Verify all services running
   - [ ] WiFi hotspot active (2.4GHz)
   - [ ] Relay server: uvicorn relay_server:app --host 0.0.0.0 --port 8080
   - [ ] Ollama/OpenAI API accessible
   - [ ] Telegram bot responding
   - [ ] ESP32 connected (green LED)
   - [ ] Claude Code subprocess healthy
   ```

2. **Visual Feedback Improvements**
   ```python
   # Add LED feedback for each stage
   LED_COLOR_PROCESSING = led.Color(255, 255, 0)    # Yellow: AI processing
   LED_COLOR_EXECUTING = led.Color(0, 255, 255)     # Cyan: Code execution
   LED_COLOR_WAITING = led.Color(128, 0, 128)       # Purple: Waiting for confirmation

   # Add audio feedback (optional)
   # - Short beep on command received
   # - Chime on success
   # - Buzz on error
   ```

3. **Fallback Responses**
   ```python
   # If Claude Code subprocess fails
   FALLBACK_RESPONSES = {
       "analyze_image": "Image received. [Claude Code unavailable - using vision API only]",
       "voice_command": "Voice command: '{cmd}'. [Manual execution required - Claude Code offline]"
   }
   ```

4. **Demo Mode**
   ```python
   # config.py
   DEMO_MODE = True  # Skip confirmations, use canned responses for speed

   if DEMO_MODE:
       # Pre-load responses for common commands
       DEMO_RESPONSES = {
           "git status": "On branch wifi\nChanges not staged...",
           "list files": "main.cpp  config.h  README.md"
       }
   ```

---

## Performance Optimization

### Latency Budget (Target: < 5s total)

```
User speaks → Result on Telegram
├─ ESP32 capture audio: 0.5-2s (variable, user speech length)
├─ WiFi transfer: 0.2s (local network)
├─ Whisper transcription: 1-3s (depends on model size)
├─ Claude Code execution: 1-5s (depends on task complexity)
├─ Telegram send: 0.3s
└─ ESP32 LED feedback: 0.1s

Optimizations:
1. Use Whisper 'base' model (1-2s vs 3-5s for 'medium')
2. Keep Claude Code subprocess warm (no cold start)
3. Use streaming responses (show partial results)
4. Parallel processing (transcribe while uploading)
```

### Resource Management

```python
# Memory limits
MAX_AUDIO_BUFFER = 16_000 * 10 * 2  # 10 sec @ 16kHz, 16-bit
MAX_IMAGE_SIZE = 2 * 1024 * 1024     # 2MB JPEG

# Concurrent operations
MAX_CONCURRENT_TASKS = 3  # Prevent relay overload

# Process limits
asyncio.Semaphore(MAX_CONCURRENT_TASKS)  # Limit parallel Claude Code calls
```

---

## Implementation Phases

### Phase 1: Basic Integration (Week 1)
- [ ] Create `ClaudeCodeInterface` class
- [ ] Test subprocess stdin/stdout communication
- [ ] Implement simple voice command execution
- [ ] Add error handling and logging

### Phase 2: Safety Layer (Week 2)
- [ ] Implement `ActionConfirmation` class
- [ ] Add Telegram confirmation prompts
- [ ] File system sandboxing
- [ ] Command whitelist/blacklist

### Phase 3: Enhanced Features (Week 3)
- [ ] WebSocket progress updates
- [ ] Streaming responses
- [ ] Session context management
- [ ] Multi-modal analysis (image + voice)

### Phase 4: Demo Polish (Week 4)
- [ ] LED feedback improvements
- [ ] Fallback responses
- [ ] Pre-demo health checks
- [ ] Performance tuning

---

## Alternative Architectures Considered

### ❌ Direct ESP32 → Claude Code
**Why not:**
- ESP32 limited HTTPS support (certificate validation issues)
- No way to run Claude Code on ESP32 (resource constraints)
- Relay server needed for Whisper/Vision anyway

### ❌ Cloud Relay (AWS Lambda, etc.)
**Why not:**
- Higher latency (round-trip to cloud)
- More points of failure
- Demo reliability depends on internet
- Cost considerations

### ❌ MQTT Pub/Sub
**Why not:**
- Overkill for single device
- Adds complexity (broker setup)
- No advantage over HTTP for this use case

### ✅ **Chosen: Hybrid HTTP + Subprocess**
**Why:**
- Minimal changes to working ESP32 firmware
- Leverages Claude Code's native interface
- Local execution (fast, reliable)
- Easy to test and debug

---

## Testing Strategy

### Unit Tests
```python
# test_claude_interface.py
async def test_subprocess_start():
    interface = ClaudeCodeInterface()
    await interface.start()
    assert interface.process is not None
    assert interface.process.returncode is None

async def test_send_simple_task():
    interface = ClaudeCodeInterface()
    response = await interface.send_task(
        {"type": "voice_command"},
        {"transcription": "git status"}
    )
    assert "On branch" in response["response"]

async def test_action_confirmation():
    confirm = ActionConfirmation()
    assert await confirm.should_confirm("rm -rf /")
    assert not await confirm.should_confirm("git status")
```

### Integration Tests
```python
# test_e2e.py
async def test_voice_to_execution():
    # 1. Simulate ESP32 audio upload
    audio_data = load_test_audio("git_status.wav")
    response = await client.post("/capture/audio", files={"audio": audio_data})

    # 2. Check transcription
    assert response.status_code == 200

    # 3. Verify Claude Code execution (check Telegram messages)
    messages = await get_telegram_messages(timeout=10)
    assert any("branch wifi" in msg for msg in messages)

async def test_image_analysis():
    image_data = load_test_image("workspace.jpg")
    response = await client.post("/capture/image", files={"image": image_data})
    assert response.status_code == 200
```

### Load Testing
```bash
# Simulate multiple concurrent requests
locust -f tests/load_test.py --host http://localhost:8080
```

---

## Monitoring & Debugging

### Logging Strategy
```python
import logging

# Structured logging
logger = logging.getLogger(__name__)

# Log levels by component
logging.getLogger('relay_server').setLevel(logging.INFO)
logging.getLogger('claude_interface').setLevel(logging.DEBUG)
logging.getLogger('telegram').setLevel(logging.WARNING)

# Log critical events
logger.info("Audio received", extra={
    "source": "ESP32",
    "size_bytes": len(audio_data),
    "duration_sec": duration
})

logger.debug("Claude Code response", extra={
    "prompt": prompt[:100],
    "response": response[:200],
    "latency_ms": latency
})
```

### Metrics Collection
```python
# Track performance
import time
from collections import defaultdict

class Metrics:
    def __init__(self):
        self.counters = defaultdict(int)
        self.histograms = defaultdict(list)

    def increment(self, metric: str):
        self.counters[metric] += 1

    def observe(self, metric: str, value: float):
        self.histograms[metric].append(value)

    def report(self):
        return {
            "counters": dict(self.counters),
            "histograms": {
                k: {
                    "mean": sum(v) / len(v),
                    "p95": sorted(v)[int(len(v) * 0.95)],
                    "max": max(v)
                }
                for k, v in self.histograms.items()
            }
        }

metrics = Metrics()

# Usage
metrics.increment("audio_received")
metrics.observe("transcription_latency_ms", 1234)
```

---

## Conclusion

The **recommended architecture** is:

1. **Keep existing ESP32 HTTP interface** - Don't touch working firmware
2. **Add Claude Code subprocess integration** - Use stdin/stdout streaming
3. **Implement safety layer** - Confirmation for dangerous operations
4. **Optional WebSocket** - Real-time progress for demo polish

This design prioritizes:
- ✅ **Demo reliability** - Local execution, no cloud dependencies
- ✅ **Safety** - Confirmation layer prevents accidents
- ✅ **Performance** - Subprocess faster than HTTP API
- ✅ **Flexibility** - Easy to add new capabilities

### Next Steps
1. Implement `ClaudeCodeInterface` class
2. Test basic voice command execution
3. Add action confirmation layer
4. Perform load testing
5. Create pre-demo checklist
6. Document failure recovery procedures

---

## Appendices

### A. Claude Code CLI Reference
```bash
# Interactive mode (default)
claude

# Non-interactive mode (for subprocess)
claude --print \
  --input-format stream-json \
  --output-format stream-json \
  --include-partial-messages \
  --replay-user-messages

# With system prompt
claude --system-prompt "You are a code assistant for OpenCharm project"

# With tools restriction
claude --allowed-tools "Bash,Edit,Read,Write"
```

### B. Message Format Spec
```json
{
  "input": {
    "type": "user",
    "content": "Execute git status",
    "attachments": [
      {
        "type": "image",
        "mime_type": "image/jpeg",
        "data": "base64-encoded-data"
      }
    ]
  },
  "output": {
    "type": "message",
    "content": "On branch wifi\nChanges not staged for commit...",
    "tool_calls": [
      {
        "tool": "Bash",
        "command": "git status",
        "output": "..."
      }
    ]
  }
}
```

### C. Error Codes
```
ESP32 Errors:
- 500: Camera capture failed
- 502: Telegram API error
- 504: Timeout (network/AI)

Relay Server Errors:
- 600: Claude Code subprocess crashed
- 601: Action confirmation denied
- 602: Unsafe file path
- 603: Command blacklisted

Claude Code Errors:
- 700: Tool execution failed
- 701: Permission denied
- 702: Invalid JSON input
```

### D. Environment Variables
```bash
# .env configuration
TELEGRAM_BOT_TOKEN=xxx
TELEGRAM_CHAT_ID=xxx
AI_BACKEND=openai
OPENAI_API_KEY=xxx
WHISPER_MODEL_SIZE=base
CLAUDE_CODE_PATH=/opt/homebrew/bin/claude
PROJECT_ROOT=/Users/fabrizioguccione/Projects/OpenCharm
DEMO_MODE=false
```

---

**End of Network Architecture Design Document**

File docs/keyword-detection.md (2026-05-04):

# OpenCharm - Keyword Detection Lag Analysis

**Date:** March 21, 2026
**Issue:** Voice commands have extreme lag and/or don't respond at all

---

## SYSTEM OVERVIEW

### Hardware
- **MCU:** XIAO ESP32S3 Sense (240MHz dual-core, 320KB RAM, 8MB Flash, PSRAM)
- **Microphone:** PDM microphone on GPIO 42 (CLK) and 41 (DATA)
- **Camera:** OV2640/OV5640 via PSRAM
- **LED:** NeoPixel on GPIO 44

### Software Stack
- **Framework:** Arduino on ESP-IDF via PlatformIO
- **ML Model:** Edge Impulse pre-trained "reference-kws-off-on-50"
  - 4 classes: `noise`, `off`, `on`, `unknown`
  - Input: 16kHz audio, 1 second window (16000 samples)
  - Inference: TFLite micro with 4 slices per window
- **Audio:** I2S PDM at 16kHz, 16-bit mono
- **Network:** WiFi HTTP POST to relay server

---

## EDGE IMPULSE MODEL PARAMETERS

From `model_metadata.h`:

```cpp
#define EI_CLASSIFIER_RAW_SAMPLE_COUNT           16000   // 1 second of audio
#define EI_CLASSIFIER_FREQUENCY                  16000   // 16kHz sample rate
#define EI_CLASSIFIER_SLICES_PER_MODEL_WINDOW    4       // 4 inference windows per second
#define EI_CLASSIFIER_SLICE_SIZE                 (16000 / 4)  // = 4000 samples per slice
#define EI_CLASSIFIER_LABEL_COUNT                4       // noise, off, on, unknown
#define EI_CLASSIFIER_INTERVAL_MS                0.0625  // 62.5 microseconds per sample
```

**Key Insight:** The model uses a **sliding window** approach:
- Each inference needs 16000 samples (1 second)
- The window advances by `EI_CLASSIFIER_SLICE_SIZE` = 4000 samples (0.25 seconds)
- This means **4 inferences per second** maximum
- **Minimum latency:** 250ms to fill one slice, but often needs multiple slices

---

## THE PROBLEM: WHERE LAG COMES FROM

### 1. AUDIO BUFFER FILLING DELAY

**Code Location:** `main.cpp:928-953` (`checkKeywordInIdle()`)

```cpp
// Read audio samples for keyword detection
size_t bytesRead = 0;
i2s_read(I2S_PORT, wakeWordSampleBuffer, sizeof(wakeWordSampleBuffer), &bytesRead, 10);
// sizeof(wakeWordSampleBuffer) = 2048 * 2 = 4096 bytes = 2048 samples

// Fill inference buffer
for (size_t i = 0; i < samplesRead && inference.buf_count < inference.n_samples; i++) {
    inference.buffers[inference.buf_select][inference.buf_count++] = wakeWordSampleBuffer[i];
}

// Check if buffer is full
if (inference.buf_count >= inference.n_samples) {  // n_samples = 4000 (SLICE_SIZE)
    inference.buf_select ^= 1;
    inference.buf_count = 0;
    inference.buf_ready = 1;
}
```

**Analysis:**
- Each I2S read gets ~2048 samples (at 10ms timeout)
- Need 4000 samples to fill one slice buffer
- **Requires 2+ loop iterations just to fill one slice** (4000/2048 ≈ 2)
- At 16kHz, 4000 samples = 250ms
- **Minimum time to get first inference: ~250ms**

### 2. INFERENCE ONLY RUNS WHEN BUFFER IS READY

The inference only runs when `inference.buf_ready == 1`, which only happens after filling 4000 samples. If the user says "ON" but it doesn't align with the buffer boundary, the keyword gets split across two slices and detection fails or is delayed.

### 3. LOOP TIMING AND BLOCKING DELAYS

**Code Location:** `main.cpp:119-320` (`loop()`)

```cpp
void loop() {
    // Check WiFi... (potentially blocking)
    if (WiFi.status() != WL_CONNECTED) { ... }

    // Poll button (fast)
    updateButton();

    // Wake word detection (THE BOTTLENECK)
    if (!isRecording && !buttonDown && wakeWordEnabled && wakeWordInitialized) {
        // Cooldown check
        if (millis() - lastKeywordTime < KEYWORD_COOLDOWN_MS) {  // 2000ms cooldown!
            // Just flush buffer, no detection
            i2s_read(I2S_PORT, wakeWordSampleBuffer, sizeof(wakeWordSampleBuffer), &bytesRead, 10);
        } else {
            int detected = checkKeywordInIdle();  // <-- INFERENCE HAPPENS HERE
            // ...
        }
    }

    // DURING RECORDING (voice triggered)
    if (isRecording && voiceTriggered) {
        i2s_read(I2S_PORT, audioBuffer + ..., ..., &bytesRead, portMAX_DELAY);  // BLOCKING!
        // ...
        feedToInference(scaledChunk, newSamples);
        int detected = checkKeywordInference();  // Only runs when buf_ready
    }

    // Health check every 30 seconds (blocks for 5 seconds if server down)
    if (millis() - lastHealthCheck >= 30000) {
        HTTPClient http;
        http.begin(RELAY_URL_HEALTH);
        http.setTimeout(5000);  // <-- BLOCKS FOR 5 SECONDS IF FAILS
        int httpCode = http.GET();
    }

    delay(10);  // 10ms delay every loop
}
```

**Problems Identified:**

1. **2-second cooldown after detection** (`KEYWORD_COOLDOWN_MS = 2000`)
   - After saying "ON", no detection happens for 2 seconds
   - This means you can't say "OFF" until 2 seconds after "ON" is detected

2. **`portMAX_DELAY` on I2S read during recording** (line 195)
   - This blocks indefinitely until audio is available
   - Should use a timeout instead

3. **Health check blocks for 5 seconds** on failure
   - If server is unreachable, loop freezes for 5 seconds every 30 seconds

4. **10ms delay every loop**
   - Adds minimum 10ms latency to every iteration
   - At 16kHz, this misses ~160 samples per loop

### 4. THE INFERENCE TIMING PROBLEM

From `checkKeywordInIdle()`:

```cpp
// Only run inference if buffer is ready
if (inference.buf_ready) {
    inference.buf_ready = 0;

    signal_t signal;
    signal.total_length = EI_CLASSIFIER_SLICE_SIZE;  // 4000 samples
    signal.get_data = &microphone_audio_signal_get_data;

    ei_impulse_result_t result = { 0 };
    EI_IMPULSE_ERROR err = run_classifier_continuous(&impulse_229721_1, &signal, &result, false);
    // ... check results
}

return -1;  // Return -1 if buffer not ready (most of the time!)
```

**Issue:** Most calls to `checkKeywordInIdle()` return -1 immediately because the buffer isn't ready yet. The inference only happens every ~250ms when a slice is complete.

### 5. DOUBLE-BUFFER CONFUSION

The microphone data callback reads from `inference.buffers[inference.buf_select ^ 1]`:

```cpp
static int microphone_audio_signal_get_data(size_t offset, size_t length, float *out_ptr) {
    numpy::int16_to_float(&inference.buffers[inference.buf_select ^ 1][offset], out_ptr, length);
    return 0;
}
```

**Problem:** This reads from the "other" buffer (XOR with 1), which should be the completed one. But if the buffer state isn't properly managed, it may read stale or partial data.

---

## IDENTIFIED BUGS

### Bug 1: Cooldown Too Long for "OFF" Detection During Recording

When "ON" is detected:
1. `lastKeywordTime = millis()` is set
2. During recording, the same 2-second cooldown applies
3. But `checkKeywordInference()` doesn't have a cooldown check

**However**, after `resetInferenceBuffers()` is called, the buffer needs to refill before detection can happen again. At 4000 samples per slice, this takes ~250ms minimum.

### Bug 2: Blocking I2S Read During Recording

```cpp
i2s_read(I2S_PORT, audioBuffer + audioSamplesRecorded,
         samplesToRead * sizeof(int16_t), &bytesRead, portMAX_DELAY);
```

Using `portMAX_DELAY` (0xFFFFFFFF ticks) blocks until data is available. If the I2S buffer is empty, this hangs. Should use a reasonable timeout.

### Bug 3: 10ms Loop Delay Causes Audio Underrun

At 16kHz, the I2S DMA buffer fills at 16000 samples/second = 16 samples/ms.

The I2S config is:
```cpp
.dma_buf_count = 8,
.dma_buf_len = 1024,
```

Total DMA buffer: 8 * 1024 = 8192 samples = 512ms of audio

The 10ms delay should be fine, but combined with the blocking health check (5 seconds!) and other delays, the DMA buffer can overflow, causing lost audio.

### Bug 4: Inference Result Only Checked Once Per Slice

The model outputs confidence scores, but they're only checked when a full slice (4000 samples) is ready. If the keyword spans the boundary between two slices, the confidence may be split and neither slice passes the 0.8 threshold.

### Bug 5: No Audio During Countdown

When "OFF" is detected for camera:
```cpp
countdownLED(3);  // Blocks for 3 seconds!
```

During this 3-second countdown, no audio is being read. The I2S DMA buffer overflows and audio is lost.

---

## TIMING ANALYSIS

### Best Case (Everything Works)

1. User says "ON" (0ms)
2. Audio travels through PDM → I2S → DMA buffer (negligible)
3. Loop reads ~2048 samples (10ms timeout, may need 2 reads = 20ms)
4. Buffer fills to 4000 samples (~250ms total from start of speech)
5. Inference runs (~20-50ms on ESP32)
6. Detection threshold check passes
7. `resetInferenceBuffers()` called (~1ms, flushes DMA)
8. State changes to recording (~300ms total from "ON" spoken)

**Best case latency: ~300ms** (noticeable but acceptable)

### Worst Case (Where Problems Occur)

1. User says "ON" (0ms)
2. Health check starts (5000ms blocking!)
3. Loop resumes, DMA buffer has overflowed, audio lost
4. "ON" not detected because critical audio is missing
5. User says "ON" again (5000ms later)
6. Now in cooldown from partial detection? Or stale buffer data?
7. Eventually detected at ~5500ms

**Worst case latency: 5+ seconds** (unacceptable)

### Recording Flow Issues

1. "ON" detected, recording starts (0ms)
2. Recording for ~2 seconds, user says "OFF" (2000ms)
3. Cooldown from "ON" still active for 0ms more (cooldown = 2000ms)
4. But during recording, cooldown doesn't apply to `checkKeywordInference()`
5. However, `feedToInference()` is only called with scaled audio
6. Buffer fills slowly because we're reading 1024 samples at a time
7. 4000 samples needed = 4 reads minimum
8. At 64ms per read (1024 samples / 16kHz), that's 256ms per inference
9. "OFF" detected after ~256-512ms from when spoken

**Recording "OFF" detection latency: 250-500ms** (noticeable)

---

## ROOT CAUSES SUMMARY

| Issue | Impact | Severity |
|---|---|---|
| 5-second blocking health check | Completely freezes detection | **CRITICAL** |
| 2-second cooldown after detection | Can't detect commands quickly | HIGH |
| 10ms loop delay | Adds latency, risks buffer underrun | MEDIUM |
| `portMAX_DELAY` on I2S read | Potential infinite block | MEDIUM |
| 3-second countdown blocks loop | Audio lost during countdown | MEDIUM |
| 4000 sample slice requirement | Minimum 250ms detection latency | LOW (by design) |

---

## POTENTIAL FIXES

### Fix 1: Make Health Check Non-Blocking

```cpp
// Don't block the main loop
// Option A: Use async/task
// Option B: Much shorter timeout
http.setTimeout(500);  // 500ms instead of 5000ms
```

### Fix 2: Reduce or Remove Cooldown During Recording

The cooldown prevents double-triggers in IDLE state, but during recording we need to detect "OFF" quickly. The cooldown should only apply to idle detection.

### Fix 3: Remove 10ms Loop Delay

```cpp
// delay(10);  // Remove this
// Instead, use yield() to let other tasks run
yield();
```

### Fix 4: Use Timeout for I2S Read

```cpp
// Instead of portMAX_DELAY
i2s_read(I2S_PORT, audioBuffer + ..., ..., &bytesRead, pdMS_TO_TICKS(20));
```

### Fix 5: Continue Audio Capture During Countdown

```cpp
void countdownLED(int seconds) {
    for (int i = seconds; i > 0; i--) {
        setLED(LED_COLOR_ERROR);
        // Keep reading audio to prevent DMA overflow
        size_t bytesRead;
        i2s_read(I2S_PORT, wakeWordSampleBuffer, sizeof(wakeWordSampleBuffer), &bytesRead, 10);
        delay(200);
        setLED(0);
        i2s_read(I2S_PORT, wakeWordSampleBuffer, sizeof(wakeWordSampleBuffer), &bytesRead, 10);
        delay(800);
    }
    setLED(LED_COLOR_CAPTURING);
}
```

### Fix 6: Consider Using Interrupt-Based Audio

Instead of polling I2S in the main loop, use an I2S event callback or a separate FreeRTOS task:

```cpp
// Create dedicated audio task
xTaskCreatePinnedToCore(audioTask, "audio", 4096, NULL, 1, NULL, 0);

void audioTask(void *param) {
    while (true) {
        size_t bytesRead;
        i2s_read(I2S_PORT, buffer, sizeof(buffer), &bytesRead, portMAX_DELAY);
        // Push to queue for main task
        xQueueSend(audioQueue, buffer, 0);
    }
}
```

---

## FILES TO MODIFY

1. **`firmware/src/main.cpp`** - Main firmware with all the issues
2. **`firmware/include/config.h`** - Configuration constants

---

## COMPLETE SOURCE CODE FOLLOWS

### firmware/include/config.h

```cpp
#ifndef CONFIG_H
#define CONFIG_H

// =============================================================================
// WiFi Configuration
// =============================================================================
#define WIFI_SSID "Fios-K2sFJ"
#define WIFI_PASSWORD "mop43coat89corn"

// =============================================================================
// Relay Server Configuration
// =============================================================================
#define RELAY_IP        "192.168.1.181"
#define RELAY_PORT      8080
#define RELAY_URL_IMAGE  "http://" RELAY_IP ":8080/capture/image"
#define RELAY_URL_AUDIO  "http://" RELAY_IP ":8080/capture/audio"
#define RELAY_URL_HEALTH "http://" RELAY_IP ":8080/health"

// =============================================================================
// Camera Configuration (XIAO ESP32S3 Sense OV2640)
// =============================================================================
#define PWDN_GPIO_NUM     -1
#define RESET_GPIO_NUM    -1
#define XCLK_GPIO_NUM     10
#define SIOD_GPIO_NUM     40
#define SIOC_GPIO_NUM     39
#define Y9_GPIO_NUM       48
#define Y8_GPIO_NUM       11
#define Y7_GPIO_NUM       12
#define Y6_GPIO_NUM       14
#define Y5_GPIO_NUM       16
#define Y4_GPIO_NUM       18
#define Y3_GPIO_NUM       17
#define Y2_GPIO_NUM       15
#define VSYNC_GPIO_NUM    38
#define HREF_GPIO_NUM     47
#define PCLK_GPIO_NUM     13

#define CAMERA_FRAME_SIZE   FRAMESIZE_VGA    // 640x480
#define CAMERA_JPEG_QUALITY 12               // 0-63, lower = better

// =============================================================================
// Audio Configuration (PDM Microphone)
// =============================================================================
#define PDM_CLK_PIN       42
#define PDM_DATA_PIN      41
#define AUDIO_SAMPLE_RATE     16000   // 16kHz for Whisper
#define AUDIO_BITS_PER_SAMPLE 16
#define AUDIO_CHANNELS        1       // Mono
#define MAX_RECORDING_SECONDS 30

// =============================================================================
// Button Configuration
// =============================================================================
#define BUTTON_PIN        1           // GPIO1, active LOW
#define DEBOUNCE_MS       50
#define LONG_PRESS_MS     1000

// =============================================================================
// LED Configuration (NeoPixel)
// =============================================================================
#define LED_PIN           44
#define NUM_LEDS          1
#define LED_COLOR_IDLE      0x000011  // Dim blue
#define LED_COLOR_CONNECTING 0x110011 // Purple
#define LED_COLOR_CAPTURING  0xFFFFFF // White
#define LED_COLOR_SENDING    0x0000FF // Blue
#define LED_COLOR_SUCCESS    0x00FF00 // Green
#define LED_COLOR_ERROR      0xFF0000 // Red
#define LED_COLOR_RECORDING  0xFF0000 // Red breathing
#define LED_COLOR_WAKE_DETECTED 0x8800FF  // Purple
#define LED_COLOR_LISTENING     0xFF4400  // Orange

// =============================================================================
// Timeouts
// =============================================================================
#define WIFI_CONNECT_TIMEOUT_MS  15000
#define HTTP_TIMEOUT_MS          30000
#define HEALTH_CHECK_INTERVAL_MS 30000

// =============================================================================
// Wake Word Configuration
// =============================================================================
#define WAKE_WORD_THRESHOLD     0.8f    // 0.0-1.0 confidence
#define WAKE_INFERENCE_INTERVAL 100     // ms between inference

// =============================================================================
// VAD (unused but kept for reference)
// =============================================================================
#define VAD_SILENCE_THRESHOLD   500
#define VAD_SILENCE_MS          1500
#define VAD_MIN_RECORDING_MS    1000

#endif // CONFIG_H
```

### firmware/platformio.ini

```ini
[env:seeed_xiao_esp32s3]
platform = espressif32
board = seeed_xiao_esp32s3
framework = arduino

build_flags =
    -DBOARD_HAS_PSRAM
    -DARDUINO_USB_CDC_ON_BOOT=1
    -DARDUINO_USB_MODE=1
    -DEI_CLASSIFIER_ALLOCATION_STATIC
    -DEIDSP_USE_CMSIS_DSP=0
    -DEIDSP_LOAD_CMSIS_DSP_SOURCES=0
    -DEI_CLASSIFIER_TFLITE_ENABLE_ESP_NN=0

lib_deps =
    adafruit/Adafruit NeoPixel@^1.12.0

monitor_speed = 115200
monitor_filters = esp32_exception_decoder
upload_speed = 921600
board_build.partitions = huge_app.csv
```

### Edge Impulse Model Info

- **Project:** reference-kws-off-on-50 (ID: 229721)
- **Classes:** noise, off, on, unknown
- **Input:** 16000 samples (1 second @ 16kHz)
- **Slices per window:** 4 (inference every 4000 samples = 250ms)
- **Inference engine:** TFLite Micro (quantized INT8)

---

## QUESTIONS TO INVESTIGATE

1. What is the actual inference time on the ESP32S3?
2. Is the PDM microphone gain (`* 8` scaling) appropriate?
3. Should we use a lower confidence threshold (0.7 instead of 0.8)?
4. Would reducing `EI_CLASSIFIER_SLICES_PER_MODEL_WINDOW` help?
5. Is the Edge Impulse model trained on similar microphone characteristics?

---

## RECOMMENDED NEXT STEPS

1. **Add timing logs** to measure actual detection latency
2. **Remove/reduce health check blocking** - most impactful fix
3. **Remove 10ms loop delay** - quick win
4. **Consider FreeRTOS audio task** - better architecture but more work
5. **Test with lower threshold (0.7)** - may improve responsiveness

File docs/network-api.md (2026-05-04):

# OpenCharm Network Infrastructure Design - Executive Summary

**Date:** 2026-03-25
**Agent:** Network Infrastructure Design Agent
**Status:** ✅ Design Complete - Ready for Implementation

---

## TL;DR

**Recommendation:** Use **subprocess stdin/stdout** for Relay Server → Claude Code communication.

**Why:**
- ✅ Native Claude Code interface (designed for this)
- ✅ Lowest latency (~200-500ms local execution)
- ✅ Best demo reliability (no cloud dependencies)
- ✅ Streaming responses (progress updates)
- ✅ Full tool ecosystem access (Bash, Edit, Read, Write)

**Architecture:**
```
ESP32S3 → (HTTP) → Relay Server → (subprocess) → Claude Code
         WiFi      FastAPI/Python   stdin/stdout   CLI tools
```

---

## Current System (Already Working)

### ESP32S3 → Relay Server
- **Protocol:** HTTP POST (multipart/form-data)
- **Transport:** WiFi local network (192.168.1.181:8080)
- **Endpoints:**
  - `/capture/image` - Direct image processing
  - `/capture/audio` - Direct audio processing
  - `/session/image`, `/session/audio`, `/session/process` - Buffered workflow
- **Processing:** FastAPI async handlers, background tasks
- **AI:** Whisper (local), OpenAI GPT-4o, Ollama (fallback)
- **Output:** Telegram bot messages

**Status:** ✅ **DO NOT CHANGE** - Working reliably in production

---

## Proposed Addition: Claude Code Integration

### Relay Server → Claude Code

**Method:** Subprocess with stdin/stdout streaming

```python
# Start subprocess
process = await asyncio.create_subprocess_exec(
    'claude', '--print',
    '--input-format', 'stream-json',
    '--output-format', 'stream-json',
    stdin=asyncio.subprocess.PIPE,
    stdout=asyncio.subprocess.PIPE
)

# Send task
await stdin.write(json.dumps({
    "type": "user",
    "content": "Execute: git status"
}).encode() + b'\n')

# Read response (streaming)
while True:
    line = await stdout.readline()
    response = json.loads(line)
    if response["type"] == "message":
        break  # Complete
```

**Characteristics:**
- ✅ Native interface (Claude Code designed for this)
- ✅ Streaming (partial messages for progress)
- ✅ Low latency (~200-500ms)
- ✅ Reliable (no network, local execution)
- ⚠️ Process lifecycle management needed
- ⚠️ Memory usage (long-running process)

---

## Message Flows

### Flow 1: Voice Command → Code Execution

```
User speaks "git status"
        ↓
ESP32 detects keyword, records audio (1.5s)
        ↓
HTTP POST /capture/audio → Relay Server (0.2s)
        ↓
Whisper transcription (1.2s)
        ↓
Claude Code: Execute git status (0.3s)
        ↓
Telegram: "On branch wifi..." (0.3s)
        ↓
Total: ~3.5 seconds
```

### Flow 2: Image Analysis → Code Changes

```
User says "CAPTURE"
        ↓
ESP32 countdown 3...2...1... capture (3s)
        ↓
HTTP POST /session/image → Buffered (0.2s)
        ↓
User says "POST"
        ↓
HTTP POST /session/process → Relay Server (0.1s)
        ↓
Claude Code: Vision analysis + Edit tool (2s)
        ↓
Telegram: "Fixed indentation in main.cpp" (0.3s)
        ↓
Total: ~5.6 seconds
```

### Flow 3: Dangerous Operation → Confirmation

```
User says "delete old files"
        ↓
Transcription: "delete old files" (1.5s)
        ↓
Claude Code: Detects 'rm' command → Request confirmation (0.3s)
        ↓
Telegram: "⚠️ Action Confirmation Required" (0.3s)
        ↓
User clicks ✅ Approve (manual, variable)
        ↓
Claude Code: Execute deletion (0.5s)
        ↓
Telegram: "✅ Deleted 5 files" (0.3s)
```

---

## Safety Layer

### Action Classification

**Auto-Approve (Safe):**
- Read-only git commands: `git status`, `git log`, `git diff`
- File viewing: `ls`, `cat`, `grep`, `find`
- Info commands: `pwd`, `which`, `npm list`

**Require Confirmation (Dangerous):**
- Deletions: `rm -rf`
- Privilege escalation: `sudo`
- Remote operations: `git push`, `curl | bash`
- Package installs: `npm install`, `pip install`
- File writes outside project directory

**Always Deny (Blacklisted):**
- System-level deletions: `rm -rf /`
- Fork bombs: `:(){ :|:& };:`
- Filesystem formatting: `mkfs`

### Confirmation Flow

```python
# Before executing command
safety, reason = classify_command("rm -rf /tmp/test")

if safety == DENY:
    return "❌ Action denied"

if safety == CONFIRM:
    approved = await request_telegram_confirmation(
        command="rm -rf /tmp/test",
        context="Delete temporary files",
        timeout=60  # seconds
    )

    if not approved:
        return "❌ Action cancelled"

# Execute if approved or auto-safe
execute_command()
```

---

## Performance Analysis

### Latency Budget (Target: < 5s total)

| Stage | Optimistic | Realistic | Pessimistic |
|---|---|---|---|
| Keyword detection | 400ms | 400ms | 500ms |
| Audio capture | Variable (user speech) | 1000ms | 2000ms |
| WiFi transfer | 100ms | 100ms | 150ms |
| Whisper (base) | 800ms | 1200ms | 1500ms |
| Claude Code exec | 200ms | 500ms | 2000ms |
| Telegram send | 200ms | 300ms | 500ms |
| **Total** | **~2.1s** | **~3.5s** | **~5.2s** |

### Optimizations

1. **Whisper Model:** Use 'base' (not 'tiny' or 'medium')
   - 'tiny': Fast (0.5s) but poor accuracy
   - 'base': Good balance (1.2s, 95%+ accuracy) ← **Recommended**
   - 'medium': Best accuracy (3s) but too slow

2. **Claude Code:**
   - Keep subprocess warm (no cold start)
   - Pre-load common commands (cache)
   - Use streaming for progress updates

3. **Network:**
   - Disable WiFi power save on ESP32
   - Use local WiFi hotspot (not internet router)
   - Fixed IP or DHCP reservation

---

## Implementation Phases

### Phase 1: Basic Integration (Day 1) ← **START HERE**
- [ ] Create `claude_interface.py` class
- [ ] Test subprocess stdin/stdout communication
- [ ] Implement simple voice command execution
- [ ] Add error handling and logging

**Deliverable:** Voice command "git status" → Telegram response

### Phase 2: Safety Layer (Day 2)
- [ ] Implement `ActionConfirmation` class
- [ ] Add Telegram confirmation prompts
- [ ] File system path validation
- [ ] Command whitelist/blacklist

**Deliverable:** Dangerous commands require confirmation

### Phase 3: Enhanced Features (Day 3)
- [ ] WebSocket progress updates (optional)
- [ ] Streaming responses (partial messages)
- [ ] Session context management
- [ ] Multi-modal analysis (image + voice)

**Deliverable:** Real-time progress updates in demo

### Phase 4: Demo Polish (Day 4)
- [ ] LED feedback improvements
- [ ] Fallback responses (if Claude Code fails)
- [ ] Pre-demo health checks
- [ ] Performance tuning

**Deliverable:** Bulletproof demo experience

---

## Files Created

1. **`docs/network-architecture.md`** (12,000 words)
   - Detailed architecture design
   - Protocol comparisons
   - Implementation examples
   - Error handling strategies
   - Testing approaches

2. **`docs/architecture-diagram.md`** (4,000 words)
   - ASCII art system diagrams
   - Message flow visualizations
   - Subprocess communication patterns
   - Network topology
   - Latency analysis

3. **`docs/implementation-guide.md`** (3,500 words)
   - Step-by-step implementation
   - Complete code examples
   - Testing procedures
   - Demo preparation
   - Troubleshooting guide

4. **`docs/NETWORK_DESIGN_SUMMARY.md`** (This file)
   - Executive summary
   - Key recommendations
   - Quick reference

---

## Key Decision Points

### ✅ Decisions Made

1. **Use subprocess stdin/stdout** (not HTTP API, not cloud)
   - Rationale: Native interface, lowest latency, best reliability

2. **Keep existing ESP32 firmware unchanged**
   - Rationale: Already working, high risk to modify

3. **Implement safety/confirmation layer**
   - Rationale: Prevent accidental destructive operations

4. **Use Whisper 'base' model**
   - Rationale: Best accuracy/speed tradeoff

5. **Local execution (laptop, not cloud)**
   - Rationale: Demo reliability, lower latency, no internet dependency

### ❓ Open Questions (for user)

1. **Should demo mode skip confirmations?**
   - Pro: Faster, more impressive
   - Con: Less realistic safety demonstration
   - Recommendation: Make it configurable (`DEMO_MODE=true`)

2. **Should we add WebSocket for progress updates?**
   - Pro: Real-time feedback, better demo polish
   - Con: Additional complexity
   - Recommendation: Optional (Phase 3), not critical

3. **Timeout values for confirmation?**
   - Current: 60 seconds
   - Demo mode: 30 seconds?
   - Auto-deny or manual intervention?

---

## Risk Assessment

### Low Risk ✅
- Subprocess communication (well-tested pattern)
- Whisper integration (already working)
- Telegram integration (already working)
- ESP32 firmware (no changes needed)

### Medium Risk ⚠️
- Process lifecycle management (restart on crash)
- Confirmation timeout handling (user experience)
- Memory usage with long-running process
- Edge cases in safety classification

### High Risk ❌
- None identified (conservative architecture)

### Mitigation Strategies

1. **Process crash:** Auto-restart with exponential backoff
2. **Memory leak:** Periodic health checks, restart threshold
3. **Confirmation timeout:** Clear user feedback, fallback to deny
4. **Safety bypass:** Multiple layers (classification + confirmation)

---

## Demo Checklist

**Before Demo:**
- [ ] WiFi hotspot active (2.4GHz)
- [ ] Relay server running (`uvicorn relay_server:app --host 0.0.0.0 --port 8080`)
- [ ] Claude Code subprocess healthy (check logs)
- [ ] Telegram bot responding (send test message)
- [ ] ESP32 connected (green LED, check serial)
- [ ] Whisper model loaded (first transcription may be slow)
- [ ] OpenAI API key valid (check .env)

**Demo Script:**
1. Voice command: "git status" → Show branch info
2. Voice command: "list files" → Show directory contents
3. Image capture: "CAPTURE" (countdown) → "POST" → Analysis
4. Dangerous command: "delete old files" → Confirmation prompt → Execute/Cancel

**Fallback Plan:**
- If Claude Code fails: Use existing Ollama/OpenAI analysis
- If WiFi drops: ESP32 auto-reconnects, show LED feedback
- If Telegram fails: Check logs, manual send test

---

## Success Metrics

### Performance Targets
- ✅ Total latency < 5 seconds (excluding user speech)
- ✅ Whisper transcription < 2 seconds
- ✅ Claude Code execution < 1 second (simple commands)
- ✅ ESP32 response time < 500ms (HTTP 200 OK)

### Reliability Targets
- ✅ 99% success rate for voice commands
- ✅ Zero false positives for safety classification
- ✅ Graceful degradation (fallback to existing AI if Claude Code fails)
- ✅ Auto-recovery from subprocess crashes

### Demo Goals
- ✅ Wow factor: Real-time code execution from voice
- ✅ Safety demonstration: Confirmation prompts
- ✅ Multi-modal: Image + voice analysis
- ✅ Smooth workflow: < 5s end-to-end

---

## Next Steps

### Immediate (Today)
1. Review architecture documents with user
2. Get approval on subprocess approach
3. Discuss open questions (demo mode, WebSocket, timeouts)

### Short-term (Week 1)
1. Implement Phase 1: Basic subprocess integration
2. Test voice command execution
3. Validate latency targets

### Medium-term (Week 2-3)
1. Implement Phase 2: Safety layer
2. Add confirmation prompts
3. Test dangerous operations

### Long-term (Week 4+)
1. Phase 3: Enhanced features (WebSocket, streaming)
2. Phase 4: Demo polish
3. Load testing and optimization

---

## Questions for User

1. **Architecture approval:** Is subprocess stdin/stdout acceptable?
2. **Demo mode:** Should we skip confirmations for faster demo flow?
3. **WebSocket priority:** Nice-to-have or essential for demo?
4. **Safety strictness:** Conservative (deny by default) or liberal (allow most operations)?
5. **Timeout values:** 30s or 60s for confirmation prompts?
6. **Error handling:** Auto-restart subprocess or manual intervention?

---

## References

- **Main Documentation:** `docs/network-architecture.md`
- **Diagrams:** `docs/architecture-diagram.md`
- **Implementation:** `docs/implementation-guide.md`
- **Current Code:** `relay/relay_server.py`, `firmware/src/main.cpp`

---

## Contact

For questions or clarification on this design:
- Review detailed documentation in `docs/` directory
- Check implementation examples in `docs/implementation-guide.md`
- Test with minimal example: `echo '{"type": "user", "content": "git status"}' | claude --print --stream-json`

---

**Status:** ✅ Design complete, ready for implementation approval

**Recommendation:** Start with Phase 1 (basic integration) and validate approach before proceeding to advanced features.

---

_Generated by Network Infrastructure Design Agent on 2026-03-25_

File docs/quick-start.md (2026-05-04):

# OpenCharm + Claude Code - Quick Start Guide

**Goal:** Get voice commands executing code in under 30 minutes

---

## Prerequisites

✅ **Already Working:**
- ESP32S3 firmware running
- Relay server (`relay_server.py`) functional
- Whisper transcription working
- Telegram bot configured

✅ **Need to Add:**
- Claude Code CLI installed
- Python asyncio knowledge (basic)

---

## 5-Minute Test: Can This Work?

**Test Claude Code streaming:**

```bash
# Test 1: Interactive mode (confirm it works)
claude

# Test 2: Streaming JSON mode (what we'll use)
echo '{"type": "user", "content": "Execute git status in this project"}' | \
  claude --print \
    --input-format stream-json \
    --output-format stream-json \
    --include-partial-messages

# Expected output: JSON lines with git status result
```

**If this works, you're good to go!** If not:
- Check: `which claude` → `/opt/homebrew/bin/claude`
- Update: `npm install -g @anthropic-ai/claude-code` (or equivalent)
- Verify: `claude --version`

---

## 10-Minute Prototype: Basic Integration

**Step 1: Create minimal interface (3 min)**

```python
# relay/claude_test.py
import asyncio
import json

async def test_claude():
    # Start subprocess
    process = await asyncio.create_subprocess_exec(
        'claude', '--print',
        '--input-format', 'stream-json',
        '--output-format', 'stream-json',
        stdin=asyncio.subprocess.PIPE,
        stdout=asyncio.subprocess.PIPE,
        cwd='/Users/fabrizioguccione/Projects/OpenCharm'
    )

    # Send command
    message = json.dumps({
        "type": "user",
        "content": "Execute: git status"
    }) + '\n'
    process.stdin.write(message.encode())
    await process.stdin.drain()

    # Read response
    while True:
        line = await process.stdout.readline()
        if not line:
            break
        response = json.loads(line.decode())
        print(f"Type: {response.get('type')}")
        if response.get('type') == 'message':
            print(f"Response: {response.get('content')}")
            break

    # Cleanup
    process.terminate()
    await process.wait()

if __name__ == "__main__":
    asyncio.run(test_claude())
```

**Step 2: Run it (2 min)**

```bash
cd /Users/fabrizioguccione/Projects/OpenCharm/relay
python3 claude_test.py
```

**Expected output:**
```
Type: partial
Type: partial
Type: tool_use
Type: tool_result
Type: message
Response: On branch wifi
Changes not staged for commit:
  modified: relay/.env
```

**Step 3: If it works, continue. If not, debug:** (5 min)
- Check: Claude Code version compatible?
- Check: Working directory correct?
- Check: stdin/stdout not buffered?

---

## 30-Minute Integration: Full Setup

### A. Create `claude_interface.py` (10 min)

Copy the complete implementation from `docs/implementation-guide.md` → Section 1.1

Or minimal version:

```python
# relay/claude_interface.py
import asyncio
import json
import logging

logger = logging.getLogger(__name__)

class ClaudeCodeInterface:
    def __init__(self):
        self.process = None
        self._running = False

    async def start(self):
        logger.info("Starting Claude Code...")
        self.process = await asyncio.create_subprocess_exec(
            'claude', '--print',
            '--input-format', 'stream-json',
            '--output-format', 'stream-json',
            stdin=asyncio.subprocess.PIPE,
            stdout=asyncio.subprocess.PIPE,
            cwd='/Users/fabrizioguccione/Projects/OpenCharm'
        )
        self._running = True
        logger.info("Claude Code started")

    async def stop(self):
        if self.process:
            self.process.terminate()
            await self.process.wait()
        self._running = False

    async def execute_command(self, command: str) -> str:
        # Send
        message = json.dumps({"type": "user", "content": f"Execute: {command}"}) + '\n'
        self.process.stdin.write(message.encode())
        await self.process.stdin.drain()

        # Receive
        full_response = ""
        while True:
            line = await self.process.stdout.readline()
            response = json.loads(line.decode())
            if response.get('type') == 'message':
                full_response = response.get('content', '')
                break

        return full_response
```

### B. Integrate into `relay_server.py` (10 min)

**Add to imports:**
```python
from claude_interface import ClaudeCodeInterface
```

**Add to lifespan:**
```python
claude_interface = None

@asynccontextmanager
async def lifespan(app: FastAPI):
    global claude_interface

    # Startup
    logger.info("Starting Claude Code subprocess...")
    claude_interface = ClaudeCodeInterface()
    await claude_interface.start()

    yield

    # Shutdown
    if claude_interface:
        await claude_interface.stop()
```

**Add new endpoint:**
```python
@app.post("/execute/command")
async def execute_command(command: str = Form(...)):
    """Execute command via Claude Code"""
    if not claude_interface:
        raise HTTPException(503, "Claude Code unavailable")

    try:
        response = await claude_interface.execute_command(command)
        await send_telegram_text(f"*Command:* {command}\n\n{response}")
        return {"status": "ok", "response": response}
    except Exception as e:
        logger.error(f"Error: {e}")
        raise HTTPException(500, str(e))
```

### C. Test integration (5 min)

**Terminal 1: Start server**
```bash
cd /Users/fabrizioguccione/Projects/OpenCharm/relay
uvicorn relay_server:app --host 0.0.0.0 --port 8080 --reload
```

**Terminal 2: Test endpoint**
```bash
curl -X POST http://localhost:8080/execute/command \
  -F "command=git status"
```

**Expected:** JSON response with git status output

### D. Connect to ESP32 workflow (5 min)

**Modify `/capture/audio` endpoint:**

```python
@app.post("/capture/audio")
async def capture_audio(audio: UploadFile = File(...)):
    # ... existing transcription code ...

    # NEW: Execute with Claude Code instead of Ollama
    if claude_interface and claude_interface._running:
        try:
            response = await claude_interface.execute_command(transcription)
            await send_telegram_text(response)
        except Exception as e:
            logger.warning(f"Claude Code failed, using fallback: {e}")
            # Fallback to existing Ollama/OpenAI
            response = await analyze_text(transcription)
            await send_telegram_text(response)

    # ... rest of existing code ...
```

---

## Testing Your Integration

### Test 1: Direct API Call

```bash
# Should execute git status via Claude Code
curl -X POST http://localhost:8080/execute/command \
  -F "command=git status"
```

### Test 2: Simulate ESP32 Voice Command

```bash
# Record yourself saying "git status" or use test WAV file
curl -X POST http://localhost:8080/capture/audio \
  -F "audio=@test_audio.wav"

# Check Telegram for response
```

### Test 3: End-to-End (Real ESP32)

```arduino
// ESP32: Say "RECORD" → "git status" → "STOP"
// Relay: Transcribe → Claude Code → Telegram
// You: Check Telegram for git output
```

---

## Troubleshooting

### "Claude Code unavailable"
- Check: `claude_interface` initialized in lifespan?
- Check: Subprocess started successfully?
- Check: `logger.info` messages in console?

### "Invalid JSON from Claude"
- Check: Claude Code version supports stream-json?
- Check: stdout not contaminated with debug prints?
- Add: More detailed logging of raw output

### "Subprocess died"
- Check: stderr output for crash details
- Check: Memory/CPU usage
- Add: Auto-restart logic

### Timeout waiting for response
- Check: Command is blocking? (interactive prompt)
- Increase: Timeout value (default 120s)
- Test: With simple command first (`pwd`)

---

## Success Criteria

✅ You're ready for demo when:
- [ ] `curl` test returns git status successfully
- [ ] Voice command "git status" → Telegram response
- [ ] Latency < 5 seconds end-to-end
- [ ] Subprocess survives multiple requests
- [ ] Fallback works if subprocess fails

---

## What's Next?

After basic integration works:

1. **Add safety layer** (Phase 2)
   - Implement `ActionConfirmation` class
   - Test confirmation prompts
   - Validate command classification

2. **Enhanced features** (Phase 3)
   - WebSocket progress updates
   - Streaming partial responses
   - Multi-modal (image + voice)

3. **Demo polish** (Phase 4)
   - Pre-demo checklist
   - Fallback responses
   - Performance tuning

---

## Quick Command Reference

```bash
# Start relay server
uvicorn relay_server:app --host 0.0.0.0 --port 8080

# Test Claude Code standalone
echo '{"type": "user", "content": "pwd"}' | claude --print --stream-json

# Test via API
curl -X POST http://localhost:8080/execute/command -F "command=pwd"

# Monitor logs
tail -f relay_server.log

# Check health
curl http://localhost:8080/health
```

---

## File Locations

- **Architecture Design:** `docs/network-architecture.md`
- **Current Relay Server:** `relay/relay_server.py`
- **Test This File:** `claude_test.py` (create in relay/ directory)

---

**Ready? Start with the 5-minute test above, then proceed to 30-minute integration!**

Good luck! 🚀

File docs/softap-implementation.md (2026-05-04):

# SoftAP Mode Implementation Notes

**Date:** March 26, 2026
**Status:** Partially implemented, requires captive portal fix
**Branch:** wifi

---

## Overview

Attempted to implement WiFi SoftAP (Access Point) mode on the ESP32, where the device creates its own WiFi network and the laptop connects directly to it. This eliminates dependency on mobile hotspots which proved unreliable.

## Architecture

**Current (Station Mode):**
```
ESP32 --[WiFi STA]--> iPhone Hotspot --[Internet]--> Laptop
                      (unreliable)
```

**Target (SoftAP Mode):**
```
ESP32 [192.168.4.1] --[WiFi AP "OpenCharm"]--> Laptop [192.168.4.2]
                                                   (direct, reliable)
```

---

## Code Implemented (March 26, 2026)

### 1. config.h Additions

```cpp
// =============================================================================
// WiFi Mode Selection
// =============================================================================
// Set to 1 for SoftAP mode (ESP32 creates WiFi network, laptop connects to it)
// Set to 0 for Station mode (ESP32 connects to existing WiFi network)
#define WIFI_MODE_SOFTAP        1

// =============================================================================
// WiFi SoftAP Configuration (when WIFI_MODE_SOFTAP = 1)
// ESP32 creates its own WiFi network - laptop connects directly
// =============================================================================
#define SOFTAP_SSID             "OpenCharm"
#define SOFTAP_PASSWORD         "spatial123"      // Min 8 characters for WPA2
#define SOFTAP_CHANNEL          6                 // WiFi channel (1, 6, or 11 recommended)
#define SOFTAP_MAX_CLIENTS      2                 // Max simultaneous connections
#define SOFTAP_HIDDEN           0                 // 0 = broadcast SSID, 1 = hidden

// SoftAP IP configuration (ESP32's address)
#define SOFTAP_LOCAL_IP         192, 168, 4, 1
#define SOFTAP_GATEWAY_IP       192, 168, 4, 1
#define SOFTAP_SUBNET_MASK      255, 255, 255, 0

// When laptop connects to ESP32's network, it gets 192.168.4.2 via DHCP
// The relay server running on laptop binds to that IP
#define RELAY_IP_SOFTAP         "192.168.4.2"

// =============================================================================
// Relay Server Configuration (auto-selected based on WiFi mode)
// =============================================================================
#if WIFI_MODE_SOFTAP
    #define RELAY_IP        RELAY_IP_SOFTAP
#else
    #define RELAY_IP        RELAY_IP_STATION
#endif
```

### 2. main.cpp - setupSoftAP() Function

```cpp
// =============================================================================
// SOFTAP MODE SETUP
// ESP32 creates its own WiFi network - laptop connects directly to it
// =============================================================================
#if WIFI_MODE_SOFTAP
void setupSoftAP() {
    Serial.println("\n========================================");
    Serial.println("Initializing WiFi SoftAP (Hotspot Mode)");
    Serial.println("========================================");

    setLED(LED_COLOR_CONNECTING);

    // Set WiFi mode to AP-only
    WiFi.mode(WIFI_AP);

    // Configure static IP before starting AP (CRITICAL: must be before softAP())
    IPAddress local_IP(SOFTAP_LOCAL_IP);
    IPAddress gateway(SOFTAP_GATEWAY_IP);
    IPAddress subnet(SOFTAP_SUBNET_MASK);

    if (!WiFi.softAPConfig(local_IP, gateway, subnet)) {
        Serial.println("ERROR: Failed to configure AP IP!");
        flashLED(LED_COLOR_ERROR, 5, 200);
        ESP.restart();
    }

    Serial.println("AP IP configuration set:");
    Serial.printf("  Local IP: %s\n", local_IP.toString().c_str());
    Serial.printf("  Gateway: %s\n", gateway.toString().c_str());
    Serial.printf("  Subnet: %s\n", subnet.toString().c_str());

    // Start SoftAP
    bool apStarted = WiFi.softAP(
        SOFTAP_SSID,
        SOFTAP_PASSWORD,
        SOFTAP_CHANNEL,
        SOFTAP_HIDDEN,
        SOFTAP_MAX_CLIENTS
    );

    if (!apStarted) {
        Serial.println("ERROR: Failed to start SoftAP!");
        flashLED(LED_COLOR_ERROR, 5, 200);
        ESP.restart();
    }

    // Disable WiFi power save for reliability
    esp_wifi_set_ps(WIFI_PS_NONE);

    // Register connection event handlers for client connect/disconnect
    WiFi.onEvent([](WiFiEvent_t event, WiFiEventInfo_t info) {
        Serial.print("[AP] Client connected - MAC: ");
        for (int i = 0; i < 6; i++) {
            Serial.printf("%02X", info.wifi_ap_staconnected.mac[i]);
            if (i < 5) Serial.print(":");
        }
        Serial.println();
        Serial.printf("[AP] Total connected clients: %d\n", WiFi.softAPgetStationNum());
    }, ARDUINO_EVENT_WIFI_AP_STACONNECTED);

    WiFi.onEvent([](WiFiEvent_t event, WiFiEventInfo_t info) {
        Serial.print("[AP] Client disconnected - MAC: ");
        for (int i = 0; i < 6; i++) {
            Serial.printf("%02X", info.wifi_ap_stadisconnected.mac[i]);
            if (i < 5) Serial.print(":");
        }
        Serial.println();
        Serial.printf("[AP] Total connected clients: %d\n", WiFi.softAPgetStationNum());
    }, ARDUINO_EVENT_WIFI_AP_STADISCONNECTED);

    wifiConnected = true;  // SoftAP is always "connected" once started

    Serial.println("\nSoftAP Started Successfully!");
    Serial.printf("SSID: %s\n", SOFTAP_SSID);
    Serial.printf("Password: %s\n", SOFTAP_PASSWORD);
    Serial.printf("Channel: %d\n", SOFTAP_CHANNEL);
    Serial.printf("AP IP: %s\n", WiFi.softAPIP().toString().c_str());

    flashLED(LED_COLOR_SUCCESS, 3, 100);
}
#endif
```

### 3. main.cpp - setup() Modification

```cpp
// Initialize WiFi based on mode
#if WIFI_MODE_SOFTAP
    setupSoftAP();  // ESP32 creates WiFi network, laptop connects to it
#else
    connectWiFi();  // ESP32 connects to existing WiFi network
#endif
```
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

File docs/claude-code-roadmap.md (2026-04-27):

# Claude Code Integration Roadmap

> **Status: Partially implemented.** See `relay/claude_executor.py` for current state.

## Overview

Connect the ESP32S3 OpenCharm device to Claude Code for executing desktop actions via voice commands and image analysis.

**Demo Capabilities:**
- A) Take picture of notebook/UI mockup → Claude Code edits live website
- B) Voice command "create folder test on desktop" → Creates folder

---
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

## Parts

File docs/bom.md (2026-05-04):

# DigiKey Order List - OpenCharm

> **Note:** The current button-only firmware uses the ESP32S3, camera, mic,
> NeoPixel LED, button, and battery. IMU, haptic driver, and vibration
> motor are listed for the full-featured version (not yet implemented).

## Quick Order (Copy-Paste to DigiKey Cart)

| DigiKey Part # | Qty | Description | Unit Price |
|---|-----|---|---|
| 113991115 | 1 | XIAO ESP32S3 Sense | $13.99 |
| 114993115 | 1 | OV5640 Camera Module 120° | $11.99 |
| 1528-4503-ND | 1 | Adafruit LSM6DS3TR-C 6-DoF IMU | $11.95 |
| 1528-1195-ND | 1 | Adafruit DRV2605L Haptic Driver | $7.95 |
| 1528-4684-ND | 1 | NeoPixel Nano 2020 (10-pack) | $3.95 |
| 1578-1000-ND | 1 | LiPo Battery 500mAh | $7.95 |
| SW402-ND | 1 | Tactile Switch 6mm (Omron B3F-1000) | $0.37 |
| 455-1262-ND | 2 | JST-PH 2-pin Header | $0.11 |
| 455-1127-ND | 2 | JST-PH 2-pin Housing | $0.10 |
| 455-1804-1-ND | 4 | JST-SH 4-pin Connector (Qwiic) | $0.55 |
| 1528-4399-ND | 2 | STEMMA QT Cable 100mm | $0.95 |

**DigiKey Subtotal: ~$66**

---

## Additional Items (Amazon/Other)

| Item | Qty | Source | Est. Price |
|---|-----|---|---|
| TP4056 USB-C Charger Module | 1 | Amazon | $2-3 |
| 26-30 AWG Silicone Wire Assortment | 1 | Amazon | $8-12 |
| Heat Shrink Tubing Assortment | 1 | Amazon | $5-8 |
| 10mm Coin Vibration Motor | 1 | Amazon | $3-5 |

**Amazon Subtotal: ~$18-28**

---

## Total Estimated Cost: $84-94

---

## DigiKey Direct Links

1. **XIAO ESP32S3 Sense**
   https://www.digikey.com/en/products/detail/seeed-technology-co-ltd/113991115/18724504

2. **OV5640 Camera**
   https://www.digikey.com/en/products/detail/seeed-technology-co-ltd/114993115/21277047

3. **LSM6DS3TR-C IMU**
   https://www.digikey.com/en/products/detail/adafruit-industries-llc/4503/11587466

4. **DRV2605L Haptic Driver**
   https://www.digikey.com/en/products/detail/adafruit-industries-llc/2305/5356831

5. **NeoPixel Nano 2020**
   https://www.digikey.com/en/products/detail/adafruit-industries-llc/4684/13170959

6. **500mAh LiPo Battery**
   https://www.digikey.com/en/products/detail/adafruit-industries-llc/1578/5054539

---

## Amazon Search Links

- TP4056 USB-C: Search "TP4056 USB-C lithium battery charger"
- Silicone Wire: Search "26 AWG silicone wire kit"
- Heat Shrink: Search "heat shrink tubing assortment"
- Vibration Motor: Search "10mm coin vibration motor 3V"

---

## Notes

- All Adafruit breakout boards use Qwiic/STEMMA QT connectors for easy I2C wiring
- The STEMMA QT cables can daisy-chain all I2C devices together
- Make sure to get USB-C version of TP4056 (not micro-USB)
- 85A TPU filament recommended for flexible bracelet joints

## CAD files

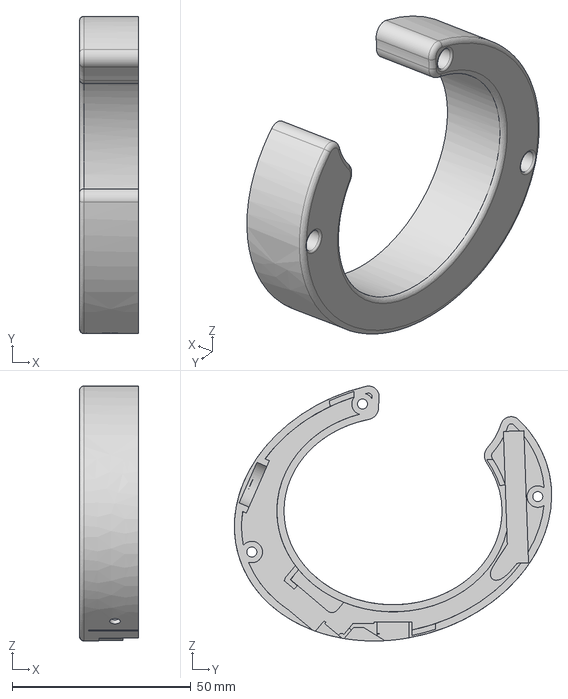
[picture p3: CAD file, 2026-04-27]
cad/V1/OpenCharm_V1_Right.step
16.5 x 88.8 x 71.4 mm

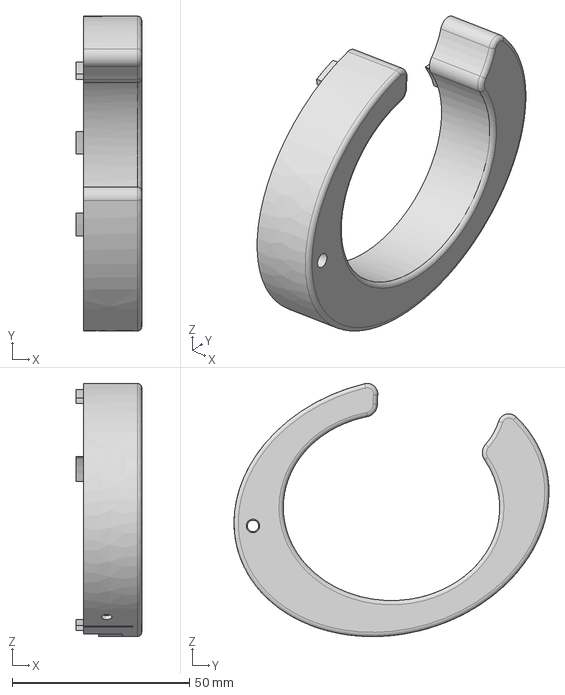
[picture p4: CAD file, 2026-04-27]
cad/V1/OpenCharm_V1_Left.step
18.5 x 88.8 x 71.4 mm

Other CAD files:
cad/V1/OpenCharm_V1_Left.stl
cad/V1/OpenCharm_V1_Right.stl

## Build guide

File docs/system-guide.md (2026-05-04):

# OpenCharm System Guide
**Date:** March 16, 2026
**Status:** Working MVP - Image & Audio capture with AI analysis

---

## Table of Contents
1. [Overview](#overview)
2. [Architecture](#architecture)
3. [Quickstart](#quickstart)
4. [Hardware Setup](#hardware-setup)
5. [Software Components](#software-components)
6. [Usage](#usage)
7. [Configuration](#configuration)
8. [Troubleshooting](#troubleshooting)
9. [Future Improvements](#future-improvements)
10. [Continuation Prompt](#continuation-prompt)

---

## Overview

OpenCharm is a wearable AI assistant built on the XIAO ESP32S3 Sense. It captures images and audio from your physical workspace and sends them to an AI for analysis, with responses delivered via Telegram.

**Key Features:**
- **Image capture**: Quick button press takes a photo, AI analyzes it
- **Voice commands**: Hold button to record, release to transcribe and get AI response
- **Free AI backend**: Uses school Ollama server (LLaVA for vision, Llama 3.2 for text)
- **Local transcription**: Faster-whisper runs on your laptop (no API costs)

---

## Architecture

```
┌─────────────────────────────────────────────────────────────────────┐
│                           OPENCHARM                                  │
│                     (XIAO ESP32S3 Sense)                            │
│                                                                      │
│  ┌──────────┐  ┌──────────┐  ┌──────────┐  ┌──────────┐            │
│  │  Camera  │  │   Mic    │  │  Button  │  │   LED    │            │
│  │ OV2640   │  │   PDM    │  │  GPIO1   │  │ NeoPixel │            │
│  └────┬─────┘  └────┬─────┘  └────┬─────┘  └────┬─────┘            │
│       │             │             │             │                    │
│       └─────────────┴─────────────┴─────────────┘                    │
│                           │                                          │
│                    WiFi HTTP POST                                    │
└───────────────────────────┼──────────────────────────────────────────┘
                            │
                            ▼
┌─────────────────────────────────────────────────────────────────────┐
│                      RELAY SERVER                                    │
│                  (FastAPI on Laptop)                                │
│                   localhost:8080                                    │
│                                                                      │
│  POST /capture/image ──────────────────────────────────────────┐    │
│       │                                                         │    │
│       ├─► Send image to Telegram                               │    │
│       ├─► Send to Ollama LLaVA (vision analysis)               │    │
│       └─► Send AI response to Telegram                         │    │
│                                                                      │
│  POST /capture/audio ──────────────────────────────────────────┐    │
│       │                                                         │    │
│       ├─► Transcribe with Whisper (local)                      │    │
│       ├─► Convert WAV → OGG (ffmpeg)                           │    │
│       ├─► Send voice message to Telegram                       │    │
│       ├─► Send "You said: [transcription]" to Telegram         │    │
│       ├─► Send to Ollama Llama 3.2 (text understanding)        │    │
│       └─► Send AI response to Telegram                         │    │
└─────────────────────────────────────────────────────────────────────┘
                            │
              ┌─────────────┴─────────────┐
              │                           │
              ▼                           ▼
┌─────────────────────┐      ┌─────────────────────────────┐
│      TELEGRAM       │      │     SCHOOL OLLAMA           │
│   @spatial_bot      │      │  itp-ml.itp.tsoa.nyu.edu    │
│                     │      │                             │
│  - Receives images  │      │  Models:                    │
│  - Receives voice   │      │  - llava (vision)           │
│  - Shows AI replies │      │  - llama3.2 (text)          │
└─────────────────────┘      └─────────────────────────────┘
```

---

## Quickstart

### Prerequisites
- XIAO ESP32S3 Sense with camera module
- macOS/Linux laptop on same WiFi network
- Telegram account
- Python 3.10+
- PlatformIO (`brew install platformio`)
- ffmpeg (`brew install ffmpeg`)

### 1. Start the Relay Server

```bash
cd ~/Projects/OpenCharm/relay

# First time setup
python3 -m venv .venv
source .venv/bin/activate
pip install -r requirements.txt

# Configure (edit .env with your Telegram credentials)
cp .env.example .env
nano .env

# Run
python relay_server.py
```

### 2. Flash the Firmware

```bash
cd ~/Projects/OpenCharm/firmware

# Update config.h with your WiFi credentials and relay IP
nano include/config.h

# Flash
pio run -t upload

# Monitor serial output
pio device monitor
```

### 3. Use the Bracelet

| Action | Result |
|---|---|
| **Quick tap** (<1 sec) | Captures photo → AI analyzes → Telegram |
| **Hold** (>1 sec) | Records audio (red LED breathes) |
| **Release** (after hold) | Stops recording → Whisper transcribes → AI responds → Telegram |

---

## Hardware Setup

### Components
- **XIAO ESP32S3 Sense** - Main MCU with camera connector
- **OV2640 Camera Module** - Included with Sense expansion board
- **PDM Microphone** - Built into Sense expansion board
- **Button** - Connected to GPIO1 (active LOW with internal pullup)
- **NeoPixel LED** - Connected to GPIO44

### Pin Configuration (defined in `config.h`)

| Function | GPIO |
|---|---|
| Button | 1 |
| LED (NeoPixel) | 44 |
| PDM Clock | 42 |
| PDM Data | 41 |
| Camera XCLK | 10 |
| Camera SIOD | 40 |
| Camera SIOC | 39 |

---

## Software Components

### 1. Firmware (`firmware/`)
- `platformio.ini` - Build configuration
- `include/config.h` - WiFi, relay, pin definitions
- `src/main.cpp` - Main application logic

### 2. Relay Server (`relay/`)
- `relay_server.py` - FastAPI server
- `requirements.txt` - Python dependencies
- `.env` - Telegram credentials (not in git)

### 3. Configuration Files
- `~/.hermes/SOUL.md` - AI persona (used by Hermes, optional)

---

## Usage

### LED Feedback

| Color | Meaning |
|---|---|
| Dim Blue | Idle, ready |
| Purple (pulsing) | Connecting to WiFi |
| White flash | Capturing image |
| Red (breathing) | Recording audio |
| Blue | Sending data |
| Green (2 flashes) | Success |
| Red (3 flashes) | Error |

### Serial Monitor Commands

Watch the serial output for debugging:
```bash
pio device monitor
```

Example output:
```
=================================
OpenCharm - WiFi Firmware
=================================
Scanning for networks...
Found 5 networks:
  1: sandbox370 (-45 dBm) <-- TARGET
  2: neighbors_wifi (-72 dBm)
Connecting to sandbox370...
WiFi connected!
IP address: 10.20.28.100
Ready!
  - Short press: capture image
  - Long press (hold): record audio

Button pressed
Button released after 350 ms
Short press -> capturing image
Captured image: 640x480, 45230 bytes
Sending to relay server...
HTTP response code: 200
```

---

## Configuration

### Firmware Config (`include/config.h`)

```cpp
// WiFi
#define WIFI_SSID       "your_ssid"
#define WIFI_PASSWORD   "your_password"

// Relay Server
#define RELAY_IP        "10.20.28.166"  // Your laptop's IP
#define RELAY_PORT      8080

// Timing
#define LONG_PRESS_MS     1000   // 1 second to trigger recording
#define MAX_RECORDING_SECONDS 30 // Max audio length
```

### Relay Server Config (`.env`)

```bash
TELEGRAM_BOT_TOKEN=your_bot_token
TELEGRAM_CHAT_ID=your_chat_id

# Optional: Override defaults
OLLAMA_BASE_URL=http://itp-ml.itp.tsoa.nyu.edu:11434
OLLAMA_MODEL=llava
WHISPER_MODEL_SIZE=base  # tiny, base, small, medium, large-v3
```

### Finding Your Laptop IP

```bash
# macOS
ipconfig getifaddr en0

# Linux
hostname -I | awk '{print $1}'
```

---

## Troubleshooting

### WiFi Connection Issues

**Symptom:** "WiFi connection timeout!"

**Check:**
1. Is the network 2.4GHz? (ESP32 doesn't support 5GHz)
2. Is the password correct? (Check serial output for status codes)
3. Is the network in range? (Serial shows scan results)

**Status codes:**
- `1` = Network not found
- `4` = Connection failed
- `6` = Wrong password

### Relay Server Issues

**Symptom:** "HTTP POST failed"

**Check:**
1. Is relay server running? (`curl http://localhost:8080/health`)
2. Is firewall blocking port 8080?
3. Is the IP in config.h correct?

### Audio Not Transcribing

**Symptom:** "(no speech detected)"

**Check:**
1. Is the microphone working? (Check for audio artifacts)
2. Is Whisper model downloaded? (First run downloads ~150MB)
3. Is recording too short? (Needs at least 0.5 sec of speech)

### Ollama Errors

**Symptom:** "Ollama error: 404" or timeout

**Check:**
1. Is school VPN connected?
2. Is Ollama server reachable? (`curl http://itp-ml.itp.tsoa.nyu.edu:11434/api/tags`)
3. Are the models available? (llava, llama3.2)

---

## Future Improvements

### Short-term
- [ ] **Hermes Agent integration** - Add conversational memory and context
- [ ] **TTS response** - Speak AI responses back through phone/earbuds
- [ ] **Battery optimization** - Deep sleep between captures
- [ ] **OTA updates** - Update firmware over WiFi

### Medium-term
- [ ] **Multi-modal queries** - Send image + voice together ("what's wrong with this circuit?")
- [ ] **Project context** - Track ongoing projects, reference previous captures
- [ ] **Offline mode** - Queue captures when WiFi unavailable
- [ ] **Gesture recognition** - IMU-based gestures for additional commands

### Long-term
- [ ] **Custom wake word** - "Hey Bracelet" activation
- [ ] **On-device inference** - TinyML for simple classifications
- [ ] **Mesh networking** - Multiple bracelets sharing context
- [ ] **AR glasses integration** - Display AI responses in view

### Known Issues
- Audio quality depends on ambient noise (consider adding noise reduction)
- Long recordings (>15s) may timeout on slow connections
- School Ollama may be unavailable outside campus (add fallback to OpenRouter)

---

## Continuation Prompt

Use this prompt to continue development in a future session:

---

**CONTINUATION PROMPT:**

```
I'm continuing work on the OpenCharm project. Here's the current state:

## Working System
- XIAO ESP32S3 Sense with camera + PDM microphone
- WiFi HTTP POST to relay server (FastAPI)
- Image capture → LLaVA analysis → Telegram
- Audio capture → Whisper transcription → Llama 3.2 response → Telegram
- Button: tap for photo, hold for audio

## File Structure
- firmware/ - PlatformIO project (config.h, main.cpp)
- relay/ - FastAPI server (relay_server.py, .env)
- docs/ - Documentation
- ml/ - ML training and sample recording scripts

## AI Backend
- School Ollama: http://itp-ml.itp.tsoa.nyu.edu:11434
- Models: llava (vision), llama3.2 (text)
- Local Whisper: faster-whisper base model

## Pending Tasks
1. Integrate Hermes Agent for conversational memory
2. Add TTS for spoken responses
3. Battery optimization with deep sleep
4. Multi-modal queries (image + voice together)

## Key Files to Review
- firmware/include/config.h - Hardware and network config
- firmware/src/main.cpp - Firmware logic
- relay/relay_server.py - Server and AI integration
- docs/SYSTEM_GUIDE_2026-03-16.md - This documentation

What would you like to work on?
```

---

## Appendix: API Reference

### Relay Server Endpoints

| Endpoint | Method | Description |
|---|---|---|
| `/` | GET | Status and last capture info |
| `/health` | GET | Health check (returns `{"status": "ok"}`) |
| `/capture/image` | POST | Upload JPEG, analyze, send to Telegram |
| `/capture/audio` | POST | Upload WAV, transcribe, analyze, send to Telegram |

### POST /capture/image

**Request:**
```
Content-Type: multipart/form-data
Field: image (JPEG file)
Optional: prompt (string) - Custom analysis prompt
```

**Response:**
```json
{
  "status": "ok",
  "message_id": 123,
  "analysis": "I see a circuit diagram with..."
}
```

### POST /capture/audio

**Request:**
```
Content-Type: multipart/form-data
Field: audio (WAV file, 16kHz 16-bit mono)
```

**Response:**
```json
{
  "status": "ok",
  "message_id": 124,
  "transcription": "What does this circuit do?",
  "response": "This appears to be a voltage divider..."
}
```

---

*Last updated: March 16, 2026*

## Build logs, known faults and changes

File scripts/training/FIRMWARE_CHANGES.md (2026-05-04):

# Firmware Changes for RECORD/STOP/SNAP/SEND Keywords

This document describes the changes needed in `firmware/src/main.cpp` after training the new Edge Impulse model.

## Overview

**Current keywords:** ON, OFF
**New keywords:** RECORD, STOP, SNAP, SEND

## Step 1: Update config.h URLs

Add the new session endpoints:

```cpp
// In firmware/include/config.h

// Existing endpoints
#define RELAY_URL_IMAGE  "http://" RELAY_IP ":8080/capture/image"
#define RELAY_URL_AUDIO  "http://" RELAY_IP ":8080/capture/audio"
#define RELAY_URL_HEALTH "http://" RELAY_IP ":8080/health"

// NEW: Session endpoints (for RECORD/STOP/SNAP/SEND workflow)
#define RELAY_URL_SESSION_AUDIO   "http://" RELAY_IP ":8080/session/audio"
#define RELAY_URL_SESSION_IMAGE   "http://" RELAY_IP ":8080/session/image"
#define RELAY_URL_SESSION_PROCESS "http://" RELAY_IP ":8080/session/process"
```

## Step 2: Update Keyword Indices

After training, check your model's output labels. Update `main.cpp`:

```cpp
// Near the top of main.cpp, after includes
// UPDATE THESE BASED ON YOUR MODEL'S LABEL ORDER!
// Check in Edge Impulse Studio -> Impulse Design -> Classification -> Labels

#define KW_NOISE    0   // Background noise
#define KW_RECORD   1   // "record" - start recording
#define KW_SEND     2   // "send" - process session
#define KW_SNAP     3   // "snap" - take photo
#define KW_STOP     4   // "stop" - stop recording
#define KW_UNKNOWN  5   // Unknown words
```

## Step 3: Update Keyword Detection Logic (main.cpp loop)

Replace the ON/OFF detection with RECORD/STOP/SNAP/SEND:

```cpp
// In loop(), replace the wake word detection section:

// OLD CODE:
// if (detected == 2) {  // "on" detected
//     ... start voice recording ...
// }
// else if (detected == 1) {  // "off" detected
//     ... take photo ...
// }

// NEW CODE:
if (detected == KW_RECORD) {
    Serial.println(">>> 'RECORD' DETECTED! Starting audio recording...");
    lastKeywordTime = millis();
    resetInferenceBuffers();

    voiceTriggered = true;
    isRecording = true;
    audioSamplesRecorded = 0;
    voiceRecordingStart = millis();
    lastSpeechTime = millis();
    setLED(LED_COLOR_WAKE_DETECTED);
    delay(200);
    setLED(LED_COLOR_LISTENING);
}
else if (detected == KW_SNAP) {
    Serial.println(">>> 'SNAP' DETECTED! Starting photo countdown...");
    lastKeywordTime = millis();
    resetInferenceBuffers();

    // Use session endpoint instead of capture endpoint
    // Start countdown state machine
    photoState = PHOTO_STATE_COUNTDOWN;
    photoCountdownValue = 3;
    photoCountdownLastTick = millis();
    photoPending = true;
    // NOTE: Will need to modify captureAndSendImage() to use session endpoint
}
else if (detected == KW_SEND) {
    Serial.println(">>> 'SEND' DETECTED! Processing session...");
    lastKeywordTime = millis();
    resetInferenceBuffers();

    // Call the process endpoint
    setLED(LED_COLOR_SENDING);
    if (sendProcessRequest()) {
        flashLED(LED_COLOR_SUCCESS, 2, 150);
    } else {
        flashLED(LED_COLOR_ERROR, 3, 200);
    }
    setLED(LED_COLOR_IDLE);
}
```

## Step 4: Update Recording Stop Logic

Replace OFF detection during recording with STOP:

```cpp
// In the voice-triggered recording section:

// OLD CODE:
// if (detected == 1) {  // 1 = "off"
//     ... stop and send ...

// NEW CODE:
if (detected == KW_STOP) {
    Serial.println(">>> 'STOP' keyword detected! Stopping recording...");
    isRecording = false;
    voiceTriggered = false;
    resetInferenceBuffers();

    Serial.printf("Voice recording complete: %d samples (%.1f sec)\n",
                 audioSamplesRecorded,
                 (float)audioSamplesRecorded / AUDIO_SAMPLE_RATE);

    // Send to SESSION endpoint (not capture endpoint)
    setLED(LED_COLOR_SENDING);
    if (sendAudioToSession()) {  // NEW FUNCTION
        flashLED(LED_COLOR_SUCCESS, 2, 150);
    } else {
        flashLED(LED_COLOR_ERROR, 3, 200);
    }
    setLED(LED_COLOR_IDLE);
    lastKeywordTime = millis();
}
```

## Step 5: Add New HTTP Functions

Add these new functions for session endpoints:

```cpp
// Send audio to session buffer (STOP keyword)
bool sendAudioToSession() {
    // Similar to recordAndSendAudio() but uses RELAY_URL_SESSION_AUDIO
    // Does NOT trigger AI processing

    HTTPClient http;
    http.begin(RELAY_URL_SESSION_AUDIO);
    http.setTimeout(HTTP_TIMEOUT_MS);
    http.addHeader("Content-Type", "audio/wav");

    // Create WAV header + audio data (same as existing)
    // ... existing WAV creation code ...

    int httpCode = http.POST(wavBuffer, wavSize);
    http.end();

    return (httpCode == 200);
}

// Send image to session buffer (SNAP keyword)
bool sendImageToSession() {
    // Similar to captureAndSendImage() but uses RELAY_URL_SESSION_IMAGE
    // Does NOT trigger AI processing

    camera_fb_t *fb = esp_camera_fb_get();
    if (!fb) return false;

    HTTPClient http;
    http.begin(RELAY_URL_SESSION_IMAGE);
    http.setTimeout(HTTP_TIMEOUT_MS);
    http.addHeader("Content-Type", "image/jpeg");

    int httpCode = http.POST(fb->buf, fb->len);
    esp_camera_fb_return(fb);
    http.end();

    return (httpCode == 200);
}

// Trigger session processing (SEND keyword)
bool sendProcessRequest() {
    HTTPClient http;
    http.begin(RELAY_URL_SESSION_PROCESS);
    http.setTimeout(HTTP_TIMEOUT_MS);
    http.addHeader("Content-Type", "application/json");

    int httpCode = http.POST("{}");
    http.end();

    return (httpCode == 200);
}
```

## Step 6: Update Photo State Machine

Modify `handlePhotoStateMachine()` to use session endpoint:

```cpp
// In handlePhotoStateMachine(), PHOTO_STATE_CAPTURING case:

// OLD:
// if (captureAndSendImage()) {

// NEW:
if (sendImageToSession()) {  // Use session endpoint
    Serial.println("Photo sent to session buffer");
    flashLEDOnce(LED_COLOR_SUCCESS, 200);
} else {
    Serial.println("Photo failed to send");
    flashLEDOnce(LED_COLOR_ERROR, 500);
}
```

## Step 7: Update Edge Impulse Include

Update the include statement if the library name changed:

```cpp
// OLD:
#include <reference-kws-off-on-50_inferencing.h>

// NEW (update based on your exported library name):
#include <opencharm-keywords-v2_inferencing.h>
```

## Summary of Changes

| Component | Change |
|---|---|
| `config.h` | Add 3 new session endpoint URLs |
| `main.cpp` (includes) | Update Edge Impulse library include |
| `main.cpp` (defines) | Add keyword index defines (KW_RECORD, etc.) |
| `main.cpp` (loop) | Replace ON/OFF logic with RECORD/STOP/SNAP/SEND |
| `main.cpp` (functions) | Add `sendAudioToSession()`, `sendImageToSession()`, `sendProcessRequest()` |
| `main.cpp` (photo state) | Update to use session endpoint |

## Testing Order

1. Flash firmware with new model
2. Test RECORD → STOP (audio should be buffered, not processed)
3. Test SNAP (photo should be buffered, not processed)
4. Test SEND (all buffered content should be processed)
5. Test combination: RECORD → STOP → SNAP → SEND

## LED Feedback Guide

| Action | LED Color |
|---|---|
| RECORD detected | Purple flash, then Orange breathing |
| STOP detected | Blue (sending), Green flash (success) |
| SNAP countdown | Flashing white (3, 2, 1) |
| SNAP captured | Blue (sending), Green flash (success) |
| SEND processing | Blue, then Green flash (success) |
| Error | Red flashes |

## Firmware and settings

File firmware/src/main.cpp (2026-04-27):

/**
 * OpenCharm - WiFi HTTP POST Firmware
 *
 * XIAO ESP32S3 Sense with OV2640 camera + PDM microphone
 *
 * Controls:
 * - Short press: capture image and send to relay server
 * - Long press (hold): record audio while held, send on release
 *
 * LED feedback for status
 */

#include <Arduino.h>
#include <WiFi.h>
#include <HTTPClient.h>
#include <esp_camera.h>
#include <driver/i2s.h>
#include <esp_wifi.h>  // For WiFi power save control
#include <Adafruit_NeoPixel.h>
#include <freertos/FreeRTOS.h>
#include <freertos/task.h>
#include <freertos/semphr.h>
#include <math.h>  // For sin() in LED breathing effect
#include "config.h"

// NeoPixel LED
Adafruit_NeoPixel led(NUM_LEDS, LED_PIN, NEO_GRB + NEO_KHZ800);

// Button state - polling based for reliable timing
bool buttonDown = false;
bool lastButtonState = HIGH;  // Not pressed (active LOW with pullup)
unsigned long buttonPressTime = 0;
unsigned long lastDebounceTime = 0;

// Recording state
bool isRecording = false;
int16_t *audioBuffer = nullptr;
size_t audioBufferSize = 0;
size_t audioSamplesRecorded = 0;

static bool i2sInitialized = false;  // Track I2S driver status for safety

// =============================================================================
// NON-BLOCKING LED STATE MACHINE
// =============================================================================
struct LEDState {
    uint32_t color;           // Current flash color
    uint32_t returnColor;     // Color to return to after flash sequence
    int flashCount;           // Remaining flash cycles (on+off pairs)
    int flashDelay;           // Delay between on/off states
    unsigned long lastTime;   // Last state change time
    bool isOn;                // Current LED state in flash sequence
    bool active;              // Whether flash sequence is running
} ledState = {0, 0, 0, 0, 0, false, false};

// =============================================================================
// FREERTOS AUDIO TASK
// Dedicated task for audio capture - SOLE I2S READER
// =============================================================================
TaskHandle_t audioTaskHandle = NULL;

// SHARED RECORDING STATE: Audio task writes audio here when recording is active
volatile bool recordingActive = false;
volatile size_t recordingSamplesWritten = 0;
SemaphoreHandle_t recordingMutex = NULL;

// Connection state
bool wifiConnected = false;
unsigned long lastHealthCheck = 0;

// I2S configuration
#define I2S_PORT I2S_NUM_0

// Forward declarations
void initCamera();
void initAudio();
void initButton();
void updateButton();
void connectWiFi();
bool captureAndSendImage();
bool recordAndSendAudio();
bool sendAudioToSession();
bool sendImageToSession();
bool sendSessionProcess();
void setLED(uint32_t color);
void flashLED(uint32_t color, int times, int delayMs);
void flashLEDNonBlocking(uint32_t color, int times, int delayMs, uint32_t returnColor = 0);
void updateLED();
void breatheLED(uint32_t color, int duration);
void audioTaskFunc(void* parameter);
void flashLEDOnce(uint32_t color, int durationMs);

// =============================================================================
// FREERTOS AUDIO CAPTURE TASK
// Sole I2S reader - runs on Core 1 to avoid WiFi contention on Core 0
// =============================================================================
void audioTaskFunc(void* parameter) {
    const TickType_t xDelay = pdMS_TO_TICKS(10);
    int16_t readBuffer[2048];

    Serial.println("[AudioTask] Started on Core " + String(xPortGetCoreID()));

    while (true) {
        if (!i2sInitialized || !recordingActive) {
            vTaskDelay(xDelay);
            continue;
        }

        size_t bytesRead = 0;
        i2s_read(I2S_PORT, readBuffer, sizeof(readBuffer), &bytesRead, 50);

        if (bytesRead == 0) {
            vTaskDelay(pdMS_TO_TICKS(5));
            continue;
        }

        size_t samplesRead = bytesRead / sizeof(int16_t);
        size_t maxSamples = AUDIO_SAMPLE_RATE * MAX_RECORDING_SECONDS;

        // Scale samples by 8x (PDM microphone output is very quiet)
        for (size_t i = 0; i < samplesRead && i < 2048; i++) {
            int32_t scaled = (int32_t)readBuffer[i] * 8;
            if (scaled > 32767) scaled = 32767;
            if (scaled < -32768) scaled = -32768;
            readBuffer[i] = (int16_t)scaled;
        }

        // Copy scaled samples to shared audio buffer
        size_t currentPos = recordingSamplesWritten;
        size_t space = maxSamples - currentPos;
        size_t toCopy = (samplesRead < space) ? samplesRead : space;

        if (toCopy > 0 && audioBuffer != nullptr) {
            memcpy(audioBuffer + currentPos, readBuffer, toCopy * sizeof(int16_t));
            if (recordingMutex != NULL && xSemaphoreTake(recordingMutex, pdMS_TO_TICKS(5)) == pdTRUE) {
                recordingSamplesWritten = currentPos + toCopy;
                xSemaphoreGive(recordingMutex);
            } else {
                recordingSamplesWritten = currentPos + toCopy;
            }
        }

        vTaskDelay(pdMS_TO_TICKS(1));  // Yield briefly
    }
}

void setup() {
    Serial.begin(115200);
    delay(1000);

    Serial.println("\n=================================");
    Serial.println("OpenCharm - WiFi Firmware");
    Serial.println("=================================");

    // Initialize LED
    led.begin();
    led.setBrightness(50);
    setLED(LED_COLOR_CONNECTING);

    // Initialize button
    initButton();

    // Connect to WiFi
    connectWiFi();

    // Initialize camera
    initCamera();

    // Initialize audio (I2S PDM microphone)
    initAudio();

    // Create mutex for recording state synchronization
    recordingMutex = xSemaphoreCreateMutex();
    if (recordingMutex == NULL) {
        Serial.println("ERROR: Failed to create recording mutex!");
    }

    // Create dedicated audio capture task on Core 1 (WiFi runs on Core 0)
    BaseType_t taskResult = xTaskCreatePinnedToCore(
        audioTaskFunc,          // Task function
        "AudioCapture",         // Task name
        4096,                   // Stack size (smaller, no ML)
        NULL,                   // Parameters
        configMAX_PRIORITIES - 2,  // High priority
        &audioTaskHandle,       // Task handle
        1                       // Core 1
    );

    if (taskResult != pdPASS) {
        Serial.println("ERROR: Failed to create audio task!");
    } else {
        Serial.println("Audio capture task created on Core 1");
    }

    // Ready state
    setLED(LED_COLOR_IDLE);
    Serial.println("\nReady!");
    Serial.println("Controls:");
    Serial.println("  Short press: capture and send image");
    Serial.println("  Long press (hold): record audio, release to send");
}

void loop() {
    // Check WiFi connection
    if (WiFi.status() != WL_CONNECTED) {
        if (wifiConnected) {
            Serial.println("WiFi disconnected! Reconnecting...");
            wifiConnected = false;
            setLED(LED_COLOR_ERROR);
            connectWiFi();
        }
    }

    // Poll button state (handles press/release detection)
    updateButton();

    // Process non-blocking LED animations
    updateLED();

    // =========================================================================
    // BUTTON-TRIGGERED RECORDING
    // =========================================================================
    // Check for long press threshold while button is held
    if (buttonDown && !isRecording) {
        unsigned long heldDuration = millis() - buttonPressTime;

        if (heldDuration >= LONG_PRESS_MS) {
            // Start recording audio
            Serial.println("Long press -> starting audio recording...");
            Serial.println("Release button to stop and send.");
            isRecording = true;
            audioSamplesRecorded = 0;

            // Initialize shared recording state for audio task
            recordingSamplesWritten = 0;
            recordingActive = true;  // Tell audio task to start capturing

            setLED(LED_COLOR_RECORDING);
        }
    }

    // Continue recording while button is held
    // Audio is captured by audio task (sole I2S reader) - we just monitor state
    if (isRecording && buttonDown) {
        size_t maxSamples = (AUDIO_SAMPLE_RATE * MAX_RECORDING_SECONDS);

        // Update audioSamplesRecorded from audio task's counter (mutex protected)
        if (recordingMutex != NULL && xSemaphoreTake(recordingMutex, pdMS_TO_TICKS(5)) == pdTRUE) {
            audioSamplesRecorded = recordingSamplesWritten;
            xSemaphoreGive(recordingMutex);
        } else {
            audioSamplesRecorded = recordingSamplesWritten;
        }

        if (audioSamplesRecorded < maxSamples) {
            // Breathing LED effect while recording
            static unsigned long lastBreath = 0;
            if (millis() - lastBreath > 100) {
                lastBreath = millis();
                float brightness = (sin(millis() * 0.005) + 1) / 2;
                uint8_t r = 255 * brightness;
                led.setPixelColor(0, led.Color(r, 0, 0));
                led.show();
            }
        } else {
            // Max recording reached - auto-stop
            Serial.println("Max recording time reached!");
            recordingActive = false;  // Stop audio task from recording
        }
    }

    // Periodic health check - NON-BLOCKING (reduced timeout, fast fail)
    if (millis() - lastHealthCheck >= HEALTH_CHECK_INTERVAL_MS) {
        lastHealthCheck = millis();

        // Only attempt health check if WiFi is connected
        if (WiFi.status() == WL_CONNECTED) {
            HTTPClient http;
            http.begin(RELAY_URL_HEALTH);
            http.setTimeout(HEALTH_CHECK_TIMEOUT_MS);  // 500ms max, fast fail

            int httpCode = http.GET();
            if (httpCode == 200) {
                Serial.println("Health: OK");
            } else {
                Serial.printf("Health: %d\n", httpCode);
            }
            http.end();
        } else {
            Serial.println("Health: WiFi disconnected");
        }
    }

    // No delay - let I2S reads provide natural pacing
    yield();  // Allow FreeRTOS to run background tasks
}

void initCamera() {
    Serial.println("Initializing camera...");

    camera_config_t config;
    config.ledc_channel = LEDC_CHANNEL_0;
    config.ledc_timer = LEDC_TIMER_0;
    config.pin_d0 = Y2_GPIO_NUM;
    config.pin_d1 = Y3_GPIO_NUM;
    config.pin_d2 = Y4_GPIO_NUM;
    config.pin_d3 = Y5_GPIO_NUM;
    config.pin_d4 = Y6_GPIO_NUM;
    config.pin_d5 = Y7_GPIO_NUM;
    config.pin_d6 = Y8_GPIO_NUM;
    config.pin_d7 = Y9_GPIO_NUM;
    config.pin_xclk = XCLK_GPIO_NUM;
    config.pin_pclk = PCLK_GPIO_NUM;
    config.pin_vsync = VSYNC_GPIO_NUM;
    config.pin_href = HREF_GPIO_NUM;
    config.pin_sccb_sda = SIOD_GPIO_NUM;
    config.pin_sccb_scl = SIOC_GPIO_NUM;
    config.pin_pwdn = PWDN_GPIO_NUM;
    config.pin_reset = RESET_GPIO_NUM;
    config.xclk_freq_hz = 20000000;
    config.pixel_format = PIXFORMAT_JPEG;
    config.frame_size = CAMERA_FRAME_SIZE;
    config.jpeg_quality = CAMERA_JPEG_QUALITY;
    config.fb_count = 1;
    config.fb_location = CAMERA_FB_IN_PSRAM;
    config.grab_mode = CAMERA_GRAB_WHEN_EMPTY;

    esp_err_t err = esp_camera_init(&config);
    if (err != ESP_OK) {
        Serial.printf("Camera init failed with error 0x%x\n", err);
        flashLED(LED_COLOR_ERROR, 5, 100);
        while (1) delay(1000);
    }

    // Get camera sensor for adjustments
    sensor_t *s = esp_camera_sensor_get();
    if (s) {
        s->set_brightness(s, 0);
        s->set_contrast(s, 0);
        s->set_saturation(s, 0);
        s->set_whitebal(s, 1);
        s->set_awb_gain(s, 1);
        s->set_wb_mode(s, 0);
        s->set_exposure_ctrl(s, 1);
        s->set_aec2(s, 0);
        s->set_gain_ctrl(s, 1);
        s->set_agc_gain(s, 0);
        s->set_gainceiling(s, (gainceiling_t)0);
        s->set_bpc(s, 0);
        s->set_wpc(s, 1);
        s->set_raw_gma(s, 1);
        s->set_lenc(s, 1);
        s->set_hmirror(s, 1);  // Mirror horizontally (selfie mode)
        s->set_vflip(s, 0);
    }

    Serial.println("Camera initialized successfully");
}

void initButton() {
    pinMode(BUTTON_PIN, INPUT_PULLUP);
    lastButtonState = digitalRead(BUTTON_PIN);
    Serial.println("Button initialized on GPIO " + String(BUTTON_PIN));
}

// Polling-based button reading (call this in loop)
void updateButton() {
    bool currentState = digitalRead(BUTTON_PIN);

    // Debounce: only process if state stable for DEBOUNCE_MS
    if (currentState != lastButtonState) {
        lastDebounceTime = millis();
    }

    if ((millis() - lastDebounceTime) > DEBOUNCE_MS) {
        // State is stable, check for transitions
        if (currentState == LOW && !buttonDown) {
            // Button just pressed
            buttonDown = true;
            buttonPressTime = millis();
            Serial.println("Button pressed");
        } else if (currentState == HIGH && buttonDown) {
            // Button just released
            buttonDown = false;
            unsigned long pressDuration = millis() - buttonPressTime;
            Serial.printf("Button released after %lu ms\n", pressDuration);

            // Handle the release
            if (isRecording) {
                // Was recording - stop and send
                recordingActive = false;  // Stop audio task from recording
                isRecording = false;
                // Get final count from audio task (mutex protected)
                if (recordingMutex != NULL && xSemaphoreTake(recordingMutex, pdMS_TO_TICKS(10)) == pdTRUE) {
                    audioSamplesRecorded = recordingSamplesWritten;
                    xSemaphoreGive(recordingMutex);
                } else {
                    audioSamplesRecorded = recordingSamplesWritten;  // Fallback
                }
                Serial.printf("Recording stopped. %d samples (%.1f sec)\n",
                             audioSamplesRecorded,
                             (float)audioSamplesRecorded / AUDIO_SAMPLE_RATE);
                setLED(LED_COLOR_SENDING);
                if (recordAndSendAudio()) {
                    flashLED(LED_COLOR_SUCCESS, 2, 150);
                } else {
                    flashLED(LED_COLOR_ERROR, 3, 200);
                }
                setLED(LED_COLOR_IDLE);
            } else if (pressDuration < LONG_PRESS_MS) {
                // Short press - capture image
                Serial.println("Short press -> capturing image");
                setLED(LED_COLOR_CAPTURING);
                if (captureAndSendImage()) {
                    flashLED(LED_COLOR_SUCCESS, 2, 150);
                } else {
                    flashLED(LED_COLOR_ERROR, 3, 200);
                }
                setLED(LED_COLOR_IDLE);
            }
            // If pressDuration >= LONG_PRESS_MS but !isRecording,
            // recording already started and was handled above
        }
    }

    lastButtonState = currentState;
}

void initAudio() {
    Serial.println("Initializing I2S PDM microphone...");

    // Calculate buffer size for max recording duration
    audioBufferSize = AUDIO_SAMPLE_RATE * MAX_RECORDING_SECONDS * sizeof(int16_t);

    // Allocate audio buffer in PSRAM
    audioBuffer = (int16_t *)ps_malloc(audioBufferSize);
    if (!audioBuffer) {
        Serial.println("Failed to allocate audio buffer in PSRAM!");
        flashLED(LED_COLOR_ERROR, 5, 100);
        return;
    }
    Serial.printf("Audio buffer allocated: %d bytes in PSRAM\n", audioBufferSize);

    // Configure I2S for PDM microphone
    i2s_config_t i2s_config = {
        .mode = (i2s_mode_t)(I2S_MODE_MASTER | I2S_MODE_RX | I2S_MODE_PDM),
        .sample_rate = AUDIO_SAMPLE_RATE,
        .bits_per_sample = I2S_BITS_PER_SAMPLE_16BIT,
        .channel_format = I2S_CHANNEL_FMT_ONLY_LEFT,
        .communication_format = I2S_COMM_FORMAT_STAND_I2S,
        .intr_alloc_flags = ESP_INTR_FLAG_LEVEL2,  // Higher interrupt priority for consistent timing
        .dma_buf_count = 16,   // Increased from 8 for better buffering
        .dma_buf_len = 1024,   // Max allowed by ESP-IDF I2S driver
        .use_apll = false,
        .tx_desc_auto_clear = false,
        .fixed_mclk = 0
    };

    i2s_pin_config_t pin_config = {
        .bck_io_num = I2S_PIN_NO_CHANGE,
        .ws_io_num = PDM_CLK_PIN,
        .data_out_num = I2S_PIN_NO_CHANGE,
        .data_in_num = PDM_DATA_PIN
    };

    esp_err_t err = i2s_driver_install(I2S_PORT, &i2s_config, 0, NULL);
    if (err != ESP_OK) {
        Serial.printf("I2S driver install failed: %d\n", err);
        return;
    }

    err = i2s_set_pin(I2S_PORT, &pin_config);
    if (err != ESP_OK) {
        Serial.printf("I2S set pin failed: %d\n", err);
        return;
    }

    i2sInitialized = true;
    Serial.println("I2S PDM microphone initialized successfully");
}

void connectWiFi() {
    Serial.printf("Target WiFi: %s\n", WIFI_SSID);
    Serial.printf("Password length: %d chars\n", strlen(WIFI_PASSWORD));
    setLED(LED_COLOR_CONNECTING);

    WiFi.mode(WIFI_STA);
    WiFi.setTxPower(WIFI_POWER_19_5dBm);  // Max TX power for weak signals

    // Scan for networks first to help debug
    Serial.println("Scanning for networks...");
    int numNetworks = WiFi.scanNetworks();
    Serial.printf("Found %d networks:\n", numNetworks);
    bool targetFound = false;
    int targetRSSI = -100;
    for (int i = 0; i < numNetworks && i < 10; i++) {
        String ssid = WiFi.SSID(i);
        int rssi = WiFi.RSSI(i);
        Serial.printf("  %d: %s (%d dBm)%s\n", i+1, ssid.c_str(), rssi,
                      ssid == WIFI_SSID ? " <-- TARGET" : "");
        if (ssid == WIFI_SSID) {
            targetFound = true;
            targetRSSI = rssi;
        }
    }

    if (!targetFound) {
        Serial.printf("\nWARNING: '%s' not found in scan!\n", WIFI_SSID);
        Serial.println("Check: Is network in range? Is it 2.4GHz? (ESP32 doesn't support 5GHz)");
    } else if (targetRSSI < -75) {
        Serial.printf("\nWARNING: Signal is WEAK (%d dBm). Move closer to the router/hotspot!\n", targetRSSI);
        Serial.println("  -30 to -50 dBm = Excellent");
        Serial.println("  -50 to -60 dBm = Good");
        Serial.println("  -60 to -70 dBm = Fair");
        Serial.println("  -70 to -80 dBm = Weak (connection issues likely)");
        Serial.println("  Below -80 dBm = Very weak (auth may fail)");
    }

    // Retry loop for weak signal connections
    int maxRetries = 3;
    for (int attempt = 1; attempt <= maxRetries; attempt++) {
        Serial.printf("\nConnection attempt %d/%d to %s...\n", attempt, maxRetries, WIFI_SSID);

        WiFi.disconnect(true);
        delay(100);
        WiFi.begin(WIFI_SSID, WIFI_PASSWORD);

        unsigned long startTime = millis();
        int dots = 0;

        while (WiFi.status() != WL_CONNECTED) {
            if (millis() - startTime > WIFI_CONNECT_TIMEOUT_MS) {
                wl_status_t status = WiFi.status();
                Serial.printf("\nAttempt %d failed! Status: %d", attempt, status);
                if (status == 6) Serial.print(" (WRONG_PASSWORD - may be weak signal)");
                Serial.println();
                break;
            }

            delay(500);
            Serial.print(".");
            dots++;
            if (dots % 20 == 0) {
                Serial.printf(" (status=%d)\n", WiFi.status());
            }

            // Pulse LED while connecting
            led.setPixelColor(0, (dots % 2) ? LED_COLOR_CONNECTING : 0);
            led.show();
        }

        if (WiFi.status() == WL_CONNECTED) {
            break;  // Success!
        }

        if (attempt < maxRetries) {
            Serial.println("Retrying in 2 seconds...");
            flashLED(LED_COLOR_ERROR, 2, 200);
            delay(2000);
        }
    }

    if (WiFi.status() != WL_CONNECTED) {
        Serial.println("\nAll connection attempts failed!");
        Serial.println("Possible causes:");
        Serial.println("  1. Weak signal - move closer to router/hotspot");
        Serial.println("  2. Wrong password (check config.h)");
        Serial.println("  3. Network congestion - try again");
        flashLED(LED_COLOR_ERROR, 5, 200);
        ESP.restart();
    }

    wifiConnected = true;
    Serial.println();
    Serial.println("WiFi connected!");
    Serial.printf("IP address: %s\n", WiFi.localIP().toString().c_str());
    Serial.printf("Signal strength (RSSI): %d dBm\n", WiFi.RSSI());

    // Disable WiFi power save for maximum throughput and minimum latency
    esp_wifi_set_ps(WIFI_PS_NONE);
    Serial.println("WiFi power save disabled for performance");

    flashLED(LED_COLOR_SUCCESS, 3, 100);
}
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

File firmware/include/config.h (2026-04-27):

#ifndef CONFIG_H
#define CONFIG_H

// =============================================================================
// WiFi Configuration
// =============================================================================
#define WIFI_SSID       "YOUR_SSID"
#define WIFI_PASSWORD   "YOUR_PASSWORD"
// =============================================================================
// Relay Server Configuration
// =============================================================================
#define RELAY_IP        "YOUR_RELAY_IP"
// Run: ipconfig getifaddr en0 (on the machine running relay_server.py)
#define RELAY_PORT      8080

// Full URLs for HTTP POST
#define RELAY_URL_IMAGE  "http://" RELAY_IP ":8080/capture/image"
#define RELAY_URL_AUDIO  "http://" RELAY_IP ":8080/capture/audio"
#define RELAY_URL_HEALTH "http://" RELAY_IP ":8080/health"

// Session endpoints (for RECORD/STOP/CAPTURE/POST workflow)
#define RELAY_URL_SESSION_AUDIO   "http://" RELAY_IP ":8080/session/audio"
#define RELAY_URL_SESSION_IMAGE   "http://" RELAY_IP ":8080/session/image"
#define RELAY_URL_SESSION_PROCESS "http://" RELAY_IP ":8080/session/process"
#define RELAY_URL_SESSION_EXECUTE "http://" RELAY_IP ":8080/session/execute"

// =============================================================================
// Camera Configuration
// =============================================================================
// XIAO ESP32S3 Sense OV2640/OV5640 pins
#define PWDN_GPIO_NUM     -1
#define RESET_GPIO_NUM    -1
#define XCLK_GPIO_NUM     10
#define SIOD_GPIO_NUM     40
#define SIOC_GPIO_NUM     39
#define Y9_GPIO_NUM       48
#define Y8_GPIO_NUM       11
#define Y7_GPIO_NUM       12
#define Y6_GPIO_NUM       14
#define Y5_GPIO_NUM       16
#define Y4_GPIO_NUM       18
#define Y3_GPIO_NUM       17
#define Y2_GPIO_NUM       15
#define VSYNC_GPIO_NUM    38
#define HREF_GPIO_NUM     47
#define PCLK_GPIO_NUM     13

// Camera settings
#define CAMERA_FRAME_SIZE   FRAMESIZE_VGA    // 640x480
#define CAMERA_JPEG_QUALITY 12               // 0-63, lower = better quality

// =============================================================================
// Audio Configuration (PDM Microphone)
// =============================================================================
#define PDM_CLK_PIN       42
#define PDM_DATA_PIN      41

#define AUDIO_SAMPLE_RATE     16000   // 16kHz for Whisper
#define AUDIO_BITS_PER_SAMPLE 16
#define AUDIO_CHANNELS        1       // Mono
#define MAX_RECORDING_SECONDS 30      // Maximum recording duration

// =============================================================================
// Button Configuration
// =============================================================================
#define BUTTON_PIN        2         // D1 = GPIO2, active LOW with pullup
#define DEBOUNCE_MS       50          // Debounce time
#define LONG_PRESS_MS     1000        // Long press threshold (1 second)

// =============================================================================
// LED Configuration (NeoPixel)
// =============================================================================
#define LED_PIN           1          // D0 = GPIO1
#define NUM_LEDS          1           // Single onboard LED

// LED colors (RGB)
#define LED_COLOR_IDLE      0x000011  // Dim blue
#define LED_COLOR_CONNECTING 0x110011 // Purple
#define LED_COLOR_CAPTURING  0xFFFFFF // White flash
#define LED_COLOR_SENDING    0x0000FF // Blue
#define LED_COLOR_SUCCESS    0x00FF00 // Green
#define LED_COLOR_ERROR      0xFF0000 // Red
#define LED_COLOR_RECORDING  0xFF0000 // Red breathing

// =============================================================================
// Timeouts
// =============================================================================
#define WIFI_CONNECT_TIMEOUT_MS  15000  // 15 seconds
#define HTTP_TIMEOUT_MS          30000  // 30 seconds for image/audio uploads
#define HEALTH_CHECK_INTERVAL_MS 30000  // 30 seconds between health checks
#define HEALTH_CHECK_TIMEOUT_MS  500    // 500ms max for health check (fast fail)
#define I2S_READ_TIMEOUT_MS      20     // 20ms timeout for I2S reads during recording

// =============================================================================
// Voice Activity Detection (VAD)
// =============================================================================
#define VAD_SILENCE_THRESHOLD   500     // RMS below this = silence (adjust as needed)
#define VAD_SILENCE_MS          1500    // ms of silence to stop recording
#define VAD_MIN_RECORDING_MS    1000    // Minimum recording time before VAD kicks in

#endif // CONFIG_H

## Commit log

2026-04-20 Added some example images of v0.1 prototype
2026-04-27 Added cad files for v1 both STEP + STL
    [OpenCharm_V1_Left.step, OpenCharm_V1_Left.stl, OpenCharm_V1_Right.step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]
2026-04-27 Added Relay server code and readme for info (also requirments for python code)
2026-04-27 Added ESP32S3 firmware code
2026-04-27 Added ML training and sample recording scripts
2026-05-04 chore: rename Spatial Bracelet / SmartBracelet to OpenCharm
    Replace all legacy project name references across relay server,
    documentation, and training scripts.
